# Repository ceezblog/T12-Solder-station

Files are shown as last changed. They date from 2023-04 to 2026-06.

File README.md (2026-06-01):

# T12-Solder-station

Just another Solder station using ATMega328 (or variant)

## 1. Main board
- Support only T12 tip that has ~4ohm~ 8ohm heater
- Only work with ATMega168, ATMega328 or newer ATMega328PB
- Use IRF4905 (P-channel) to turn on/off heat element
- Use LMV321 for amplifying thermocouple voltage, not the best but cheap and reliable
- Use buck converter mini360 and linear regulator AMS1117 for high efficiency
- Encoder to control the temperature
- Use homemade opto switch, just a pair of IR LED and IR Reciever Diode (or phototransistor)
- Only need 2 wires to the tip's heat element

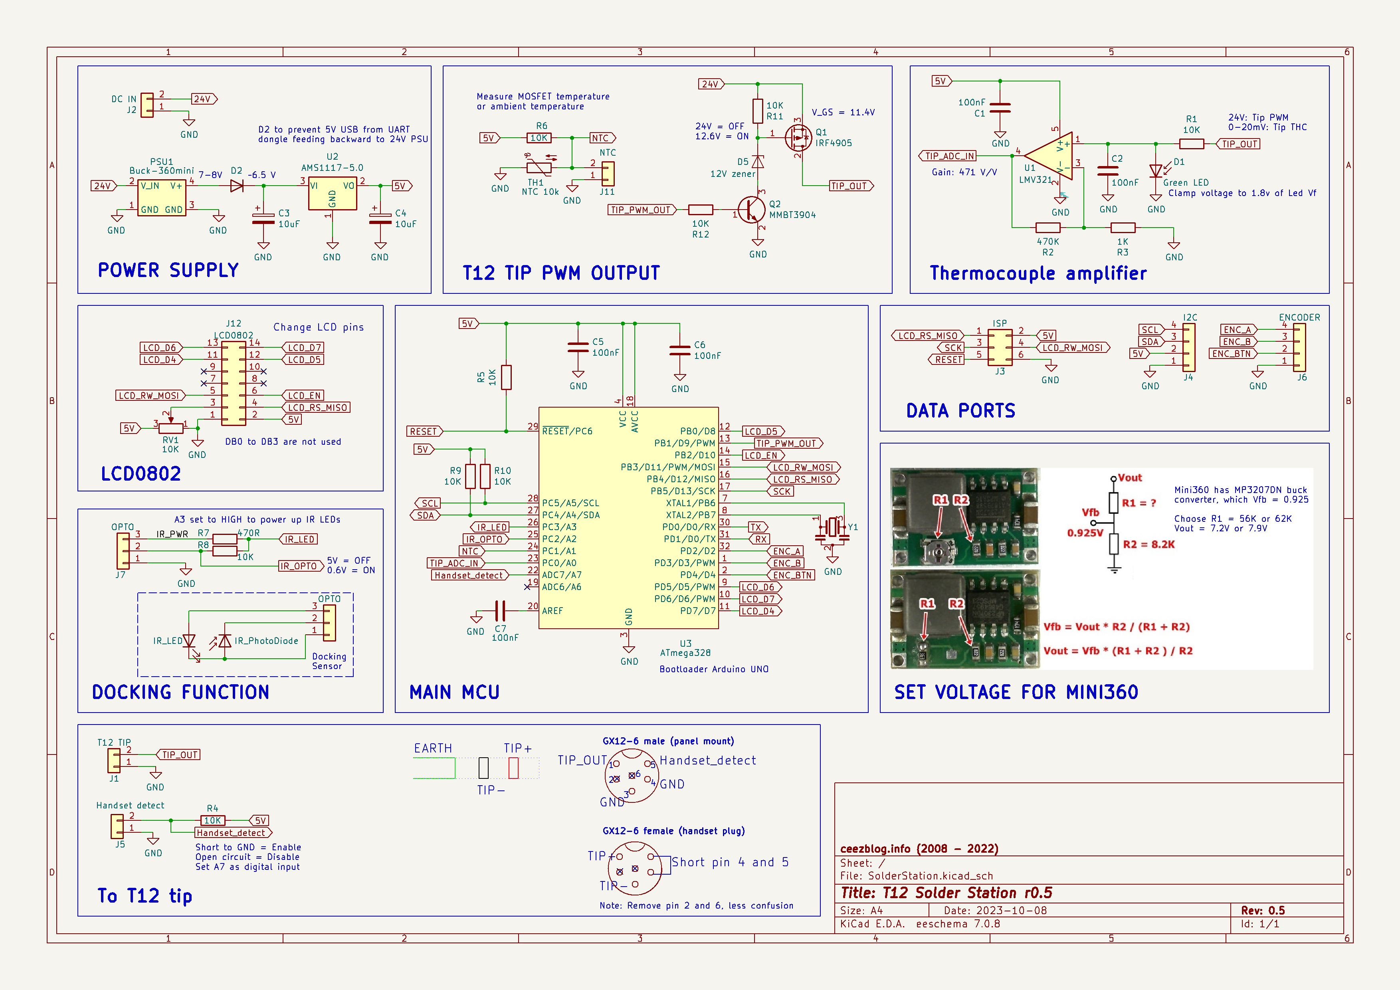
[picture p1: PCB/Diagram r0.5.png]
schematic

Pdf version here <a href='PCB/SolderStation_r0.5.pdf'>SolderStation_r0.5.pdf</a>

## 2. Switching PSU
- The 3D printed enclosure only supports this power supply model WX-DC2412, search aliexpress for "WX-DC2412 24V 4A"
- There are a few variants of this power supply have the same mounting holes which work just fine
- Always pick PSU 30% more power capable when your system full-load, ie: full-load 3A -> choose 4A PSU
- Laptop adaptor usually is 19V, using 8ohm tip -> 45w, while 24V PSU will delivery 72w at the tip
- It's better if you have earth prong from main AC 240V connect to the tip, but not neccessary
- Just a warm note: Do not attemp to modify or fix switching PSU, don't try messing with AC 240V

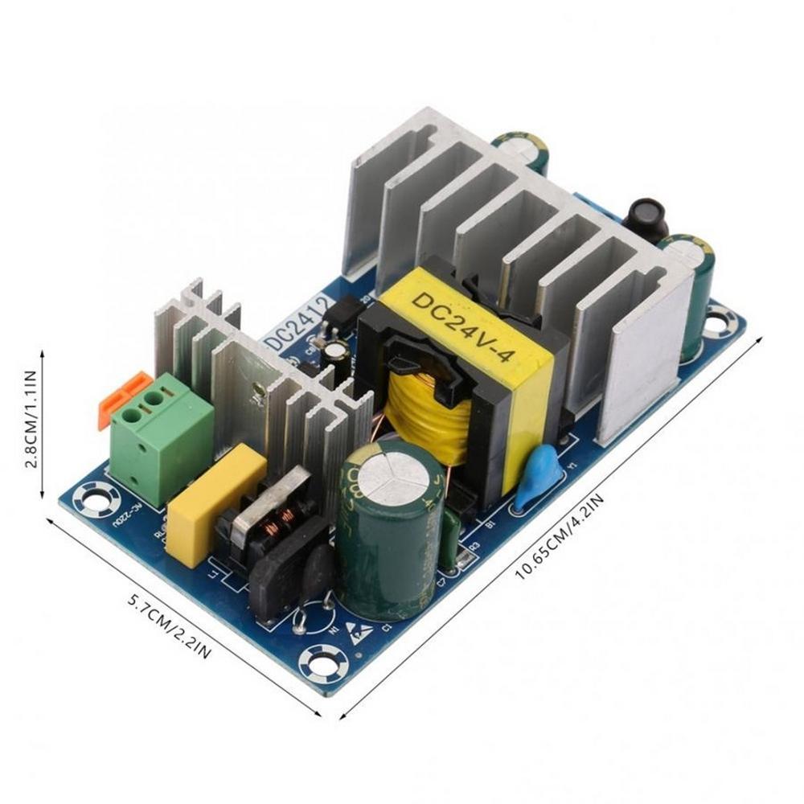
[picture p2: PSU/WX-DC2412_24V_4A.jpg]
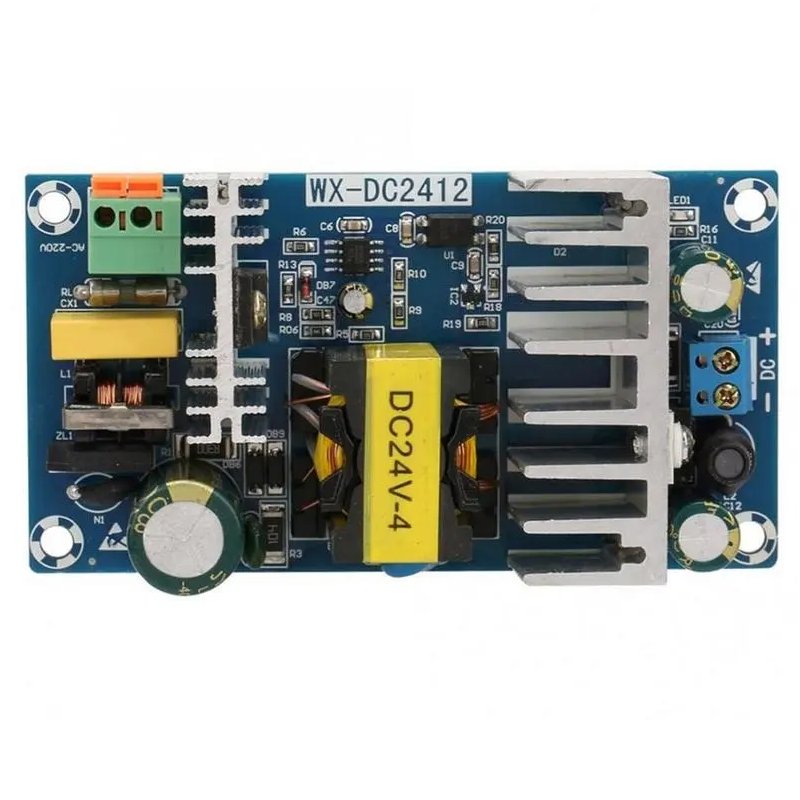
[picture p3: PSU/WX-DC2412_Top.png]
 

## 4. Display
- Only support LCD0802 - 8 char 2 line Character LCD, the main board was designed to piggyback on the LCD
- It is possible to use SSD1306 display via I2C or bitbang SPI for ILI9341 display controller but I haven't written code for this. 
- The 0802 is way nicer in my opinion
- PCB was designed for direct PCB to PCB plug-in (dupon header male and female) to the 14pin version of LCD0802
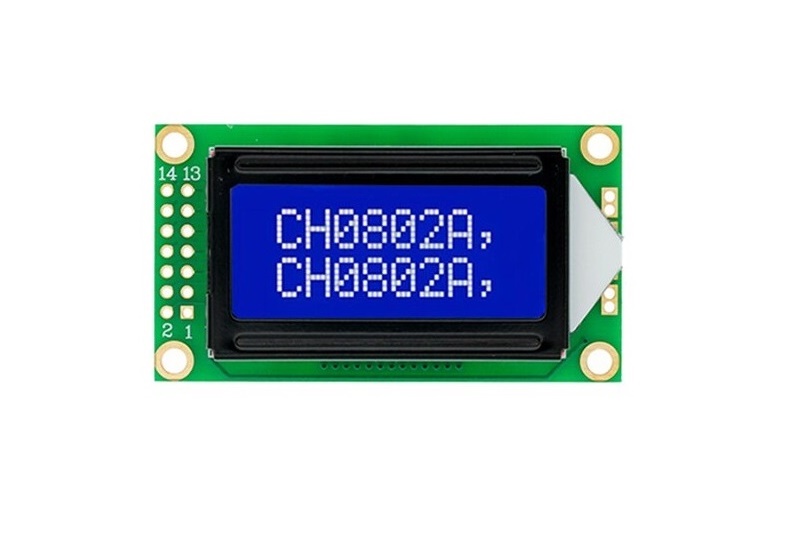
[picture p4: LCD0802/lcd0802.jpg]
LCD0802


- There is 16pin version of LCD0802, which offset the pins. This won't be direct plug-in. It can be done but a bit of hack-ish solution:
  - Solder a tall header (2x7) and bend all 14 metal pins in an awkward way so that 4 screws in the corner would be in the right spot.
  - 2 extra pins (pin 15-16) are for the backlight and are not connected to controller blob. So the code won't be able to turn on/off backlight at will. There are 2 jumpers near the backlight LED (that connects to the LED and to the controller blob), just short those 2 jumpers and don't touch other jumpers. In my case, it is J3 and J4. Different vendors have different markings.
  - While you are there, replace 0R with 330R to lower down backlight current draw as well. It probably is 100R and 0R which I find a bit high (about 25mA @ 5V for white LED). Comfortable range for a small LED like that is around 5-20mA which your eyes won't be able to tell the difference in brightness, but your phone's camera will say otherwise.

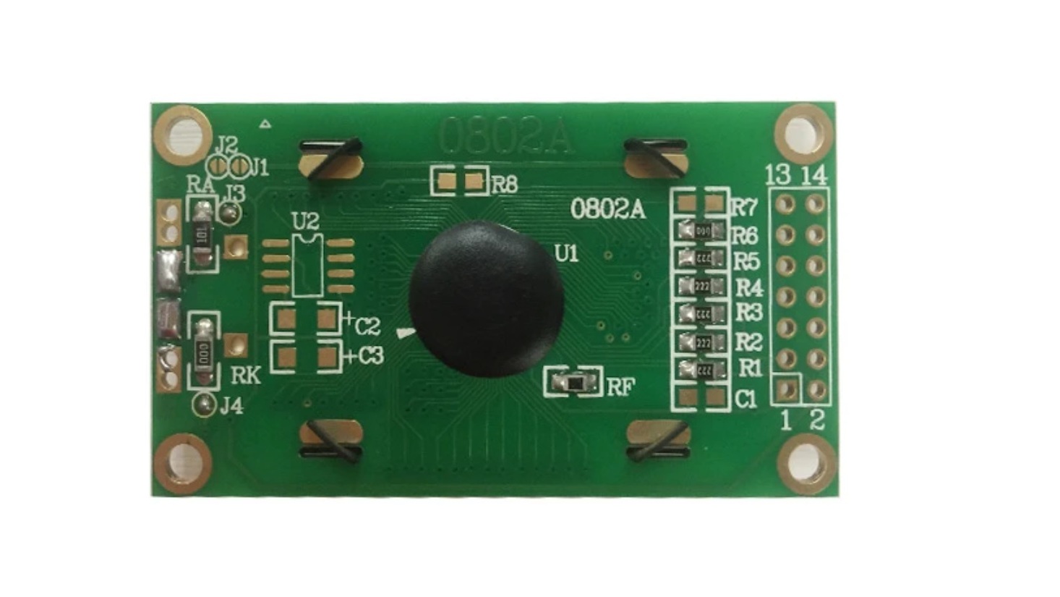
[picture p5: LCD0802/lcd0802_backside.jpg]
LCD0802_backside


## 5. Enclosure
- All 3D printed, except for the rubber feet to stop this box from sliding when pressing power button
- Housing a nice Switching PSU, no need for discrete power brick which you can't turn off from this box
- Include stand for the handle with docking mechanism using homemade opto switch
- Include opto switch housing, just need a pair of IR LED and IR receiver diode.
 
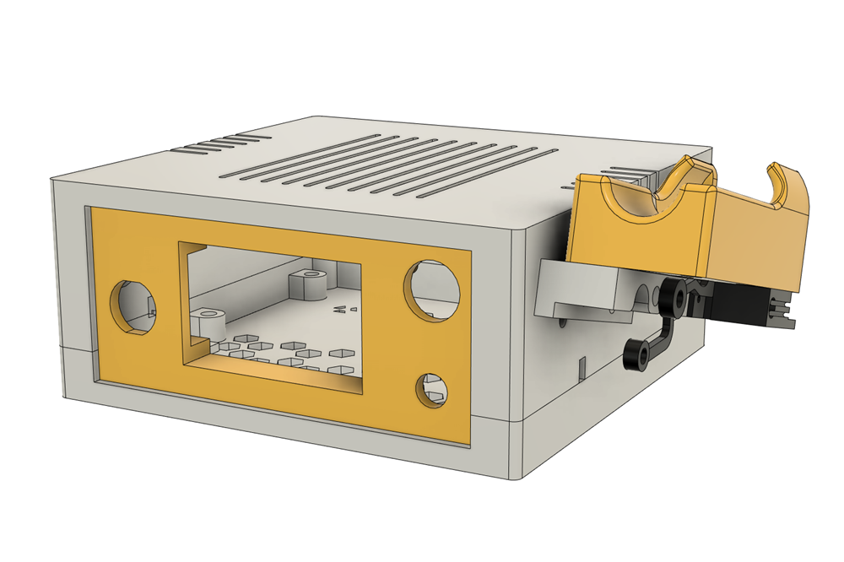
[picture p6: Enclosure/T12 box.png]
3D printed Enclosure

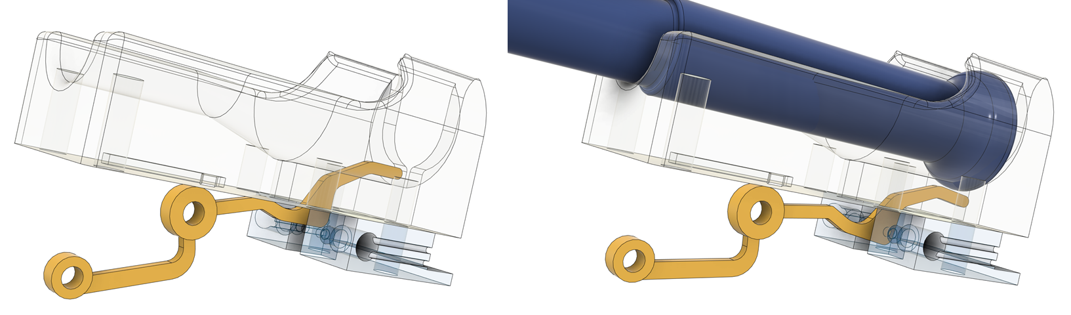
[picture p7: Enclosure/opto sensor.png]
3D printed Enclosure


## 6. Firmware and calibration
- Using Arduino IDE and MiniCore for ATMEGA328PB (new variant that you can buy readily these day - 2023) while classic Arduino is ATMEGA328
- There are main firmware and calibration firmware for you to play with your own calibration
- Only ATMega328 and variant is supported because of low level code to config timer, pwm, interrupts...
- Only three libraries are used: **avr/interrupt.h, EEPROM.h and LiquidCrystal.h**
- Thermocouple in T12 tip is unknown, not K-type nor C-type, so you can't really use off-the-shelf themocouple amplifier
- I calibrate it by tabulating ADC readings against multiple temperatures, then plotting the chart in excel to find the trend equation: T = ADC*0.403 + 49.6
- This formular only applies to the amplifier that has gain of 471V/V and 8ohm T12 tip, if you have 4ohm tip, use with caution
- The downside of 10bit ADC is we cannot measure anything below 48mV which is around 50°C
- This guy has some nice work on debunk the myth T12 tip is K-type https://hackaday.io/project/94905-hakko-revenge/log/144548-hakko-t12-thermocouple-is-not-type-k
- ~Mine is a bit glitchy with EEPROM, sometime it doesn't remember docking function is ON after power off~ I just had a bad M328PB chip
- Doesn't implement any thermal runaway protection, but code such feature is not that hard:
  + At every tick, check if temp increase while powering - Heater dead or wrong pin connected if temperature stays the same
  + Check temperature difference if too great after 3-5s heat up - Probably different thermocouple in the tip
 
## 7. T12 Handle
- It would work with pretty much any T12 handle you can buy, but the stand probably won't accept many of them
- I have 2 stand designs for handles I have, check the cross section diameter of the handle before print
- If you want the original aviation GX plug come with the handle, then just short J5 by a jumper and by-pass check for handle
- A standalone iron handle stand <a href="https://ceezblog.com/revisit-my-homemade-t12-soldering-station">blog post at ceezblog.com</a>
 
 ## 8. Put everything together
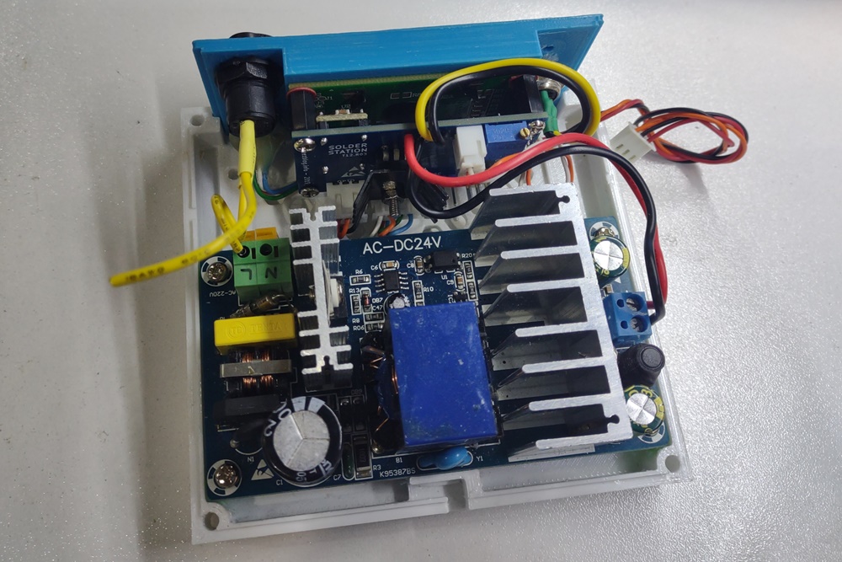
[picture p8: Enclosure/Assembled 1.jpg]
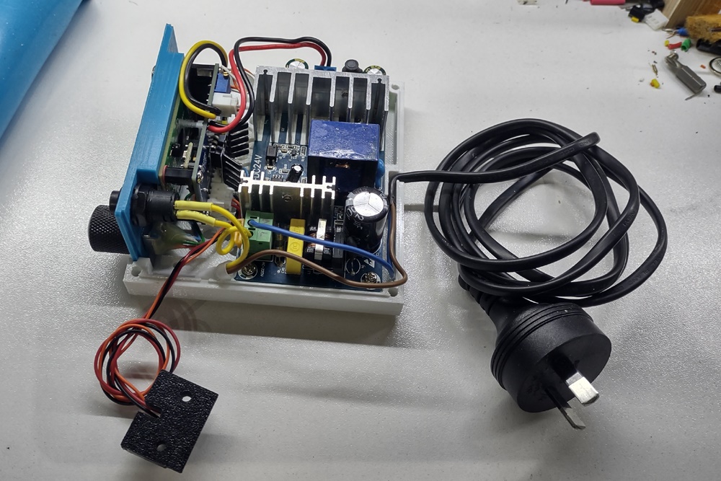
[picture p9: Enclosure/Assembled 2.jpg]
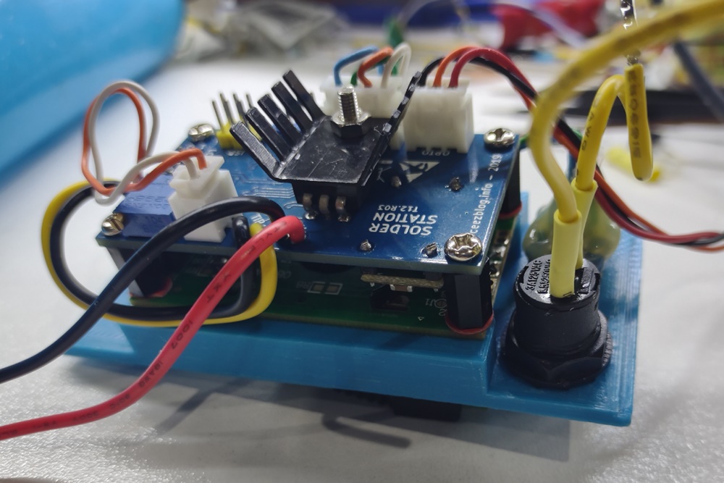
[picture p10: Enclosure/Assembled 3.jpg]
  
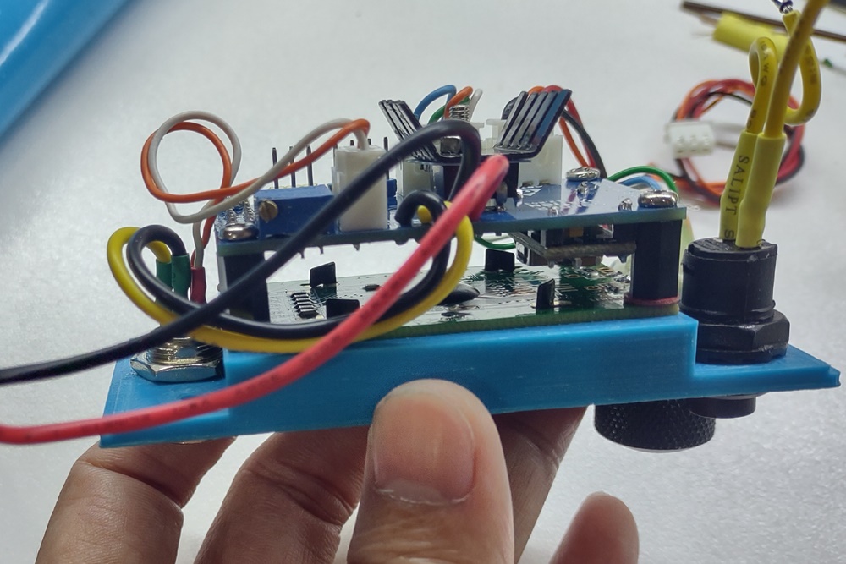
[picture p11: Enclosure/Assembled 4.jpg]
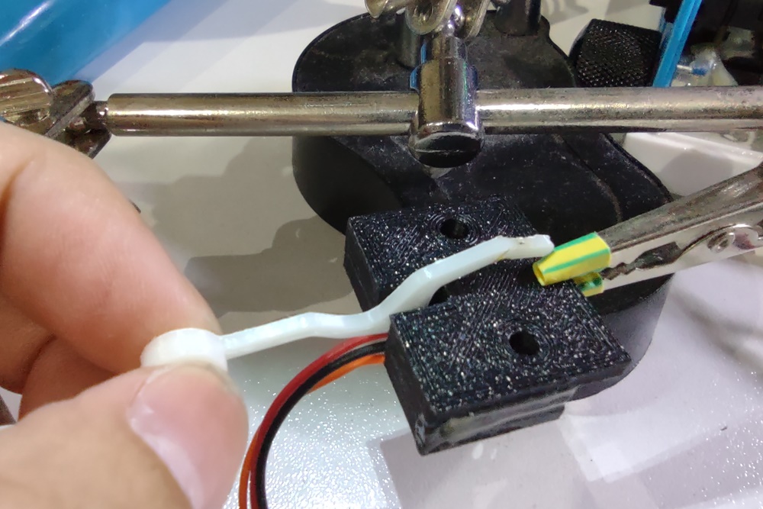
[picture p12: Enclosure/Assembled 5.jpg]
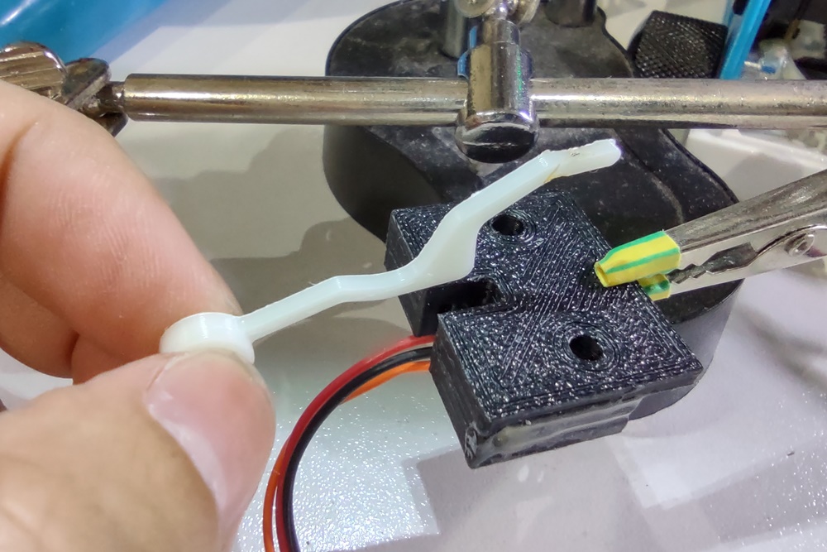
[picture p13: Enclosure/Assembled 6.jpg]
  
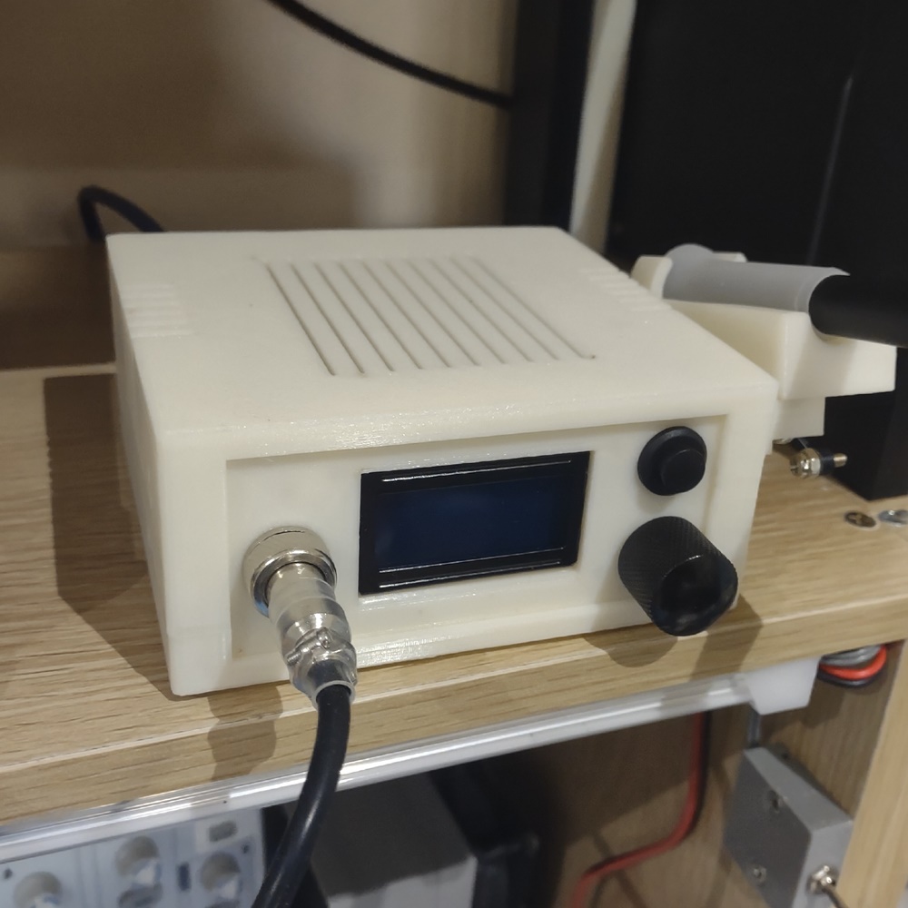
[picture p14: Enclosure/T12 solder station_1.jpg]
3D printed Enclosure
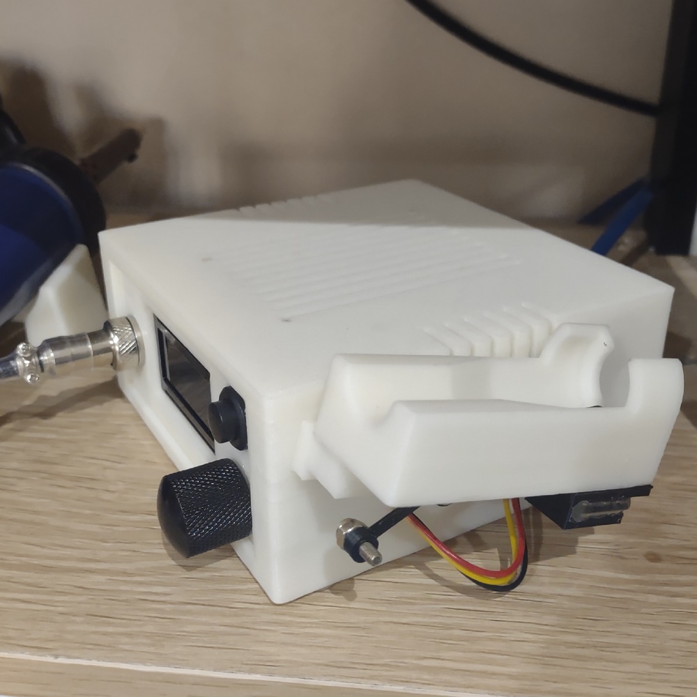
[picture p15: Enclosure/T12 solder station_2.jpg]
3D printed Enclosure
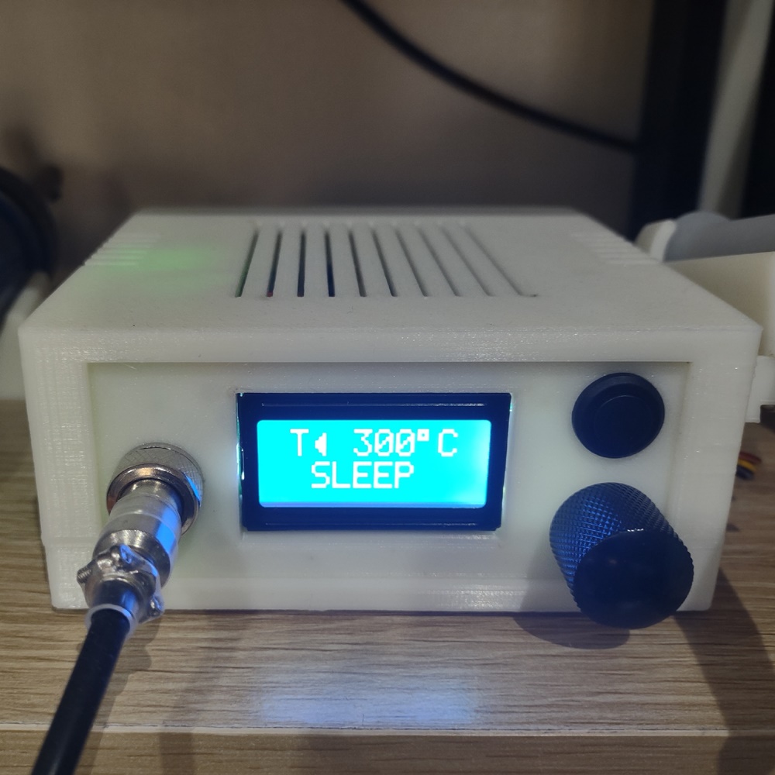
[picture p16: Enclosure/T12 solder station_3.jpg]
3D printed Enclosure
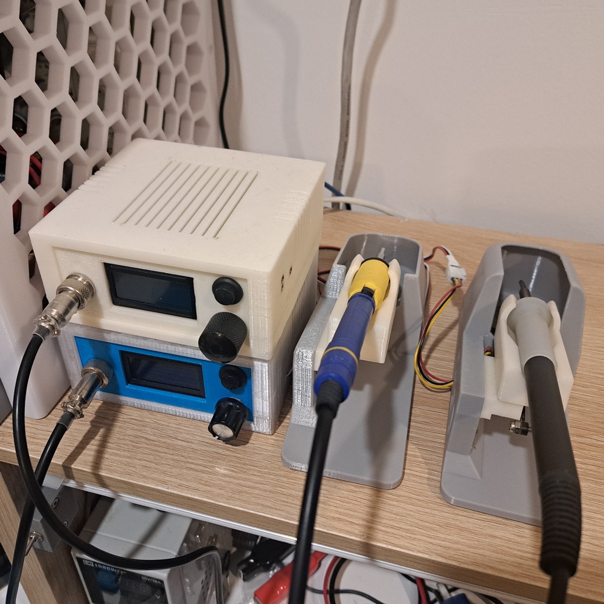
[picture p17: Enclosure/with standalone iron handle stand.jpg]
3D printed Enclosure
   3D printed Enclosure 3D printed Enclosure

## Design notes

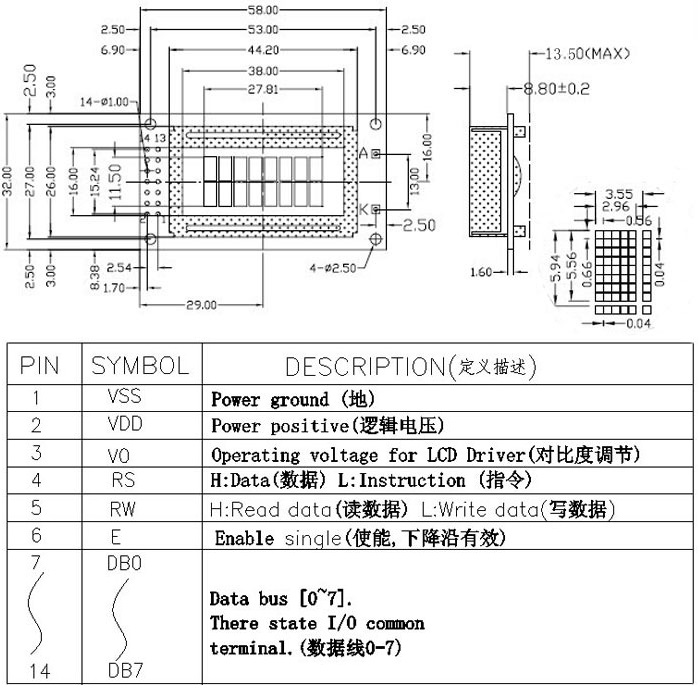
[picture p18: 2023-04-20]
LCD0802/lcd0802-0.jpg

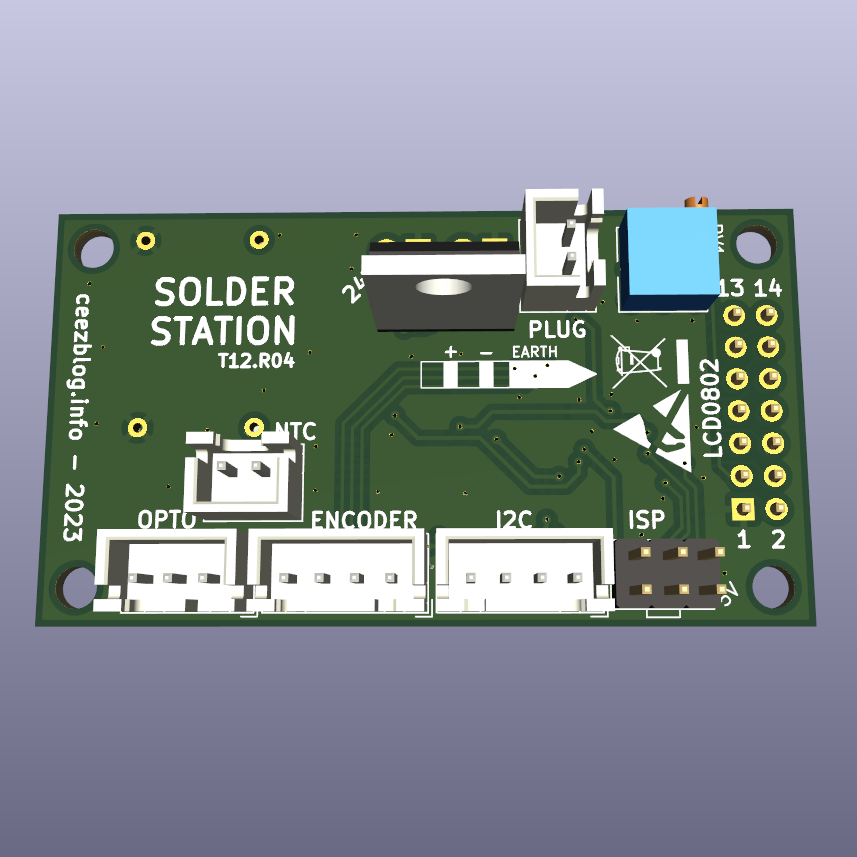
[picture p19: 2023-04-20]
PCB/Render 3.png

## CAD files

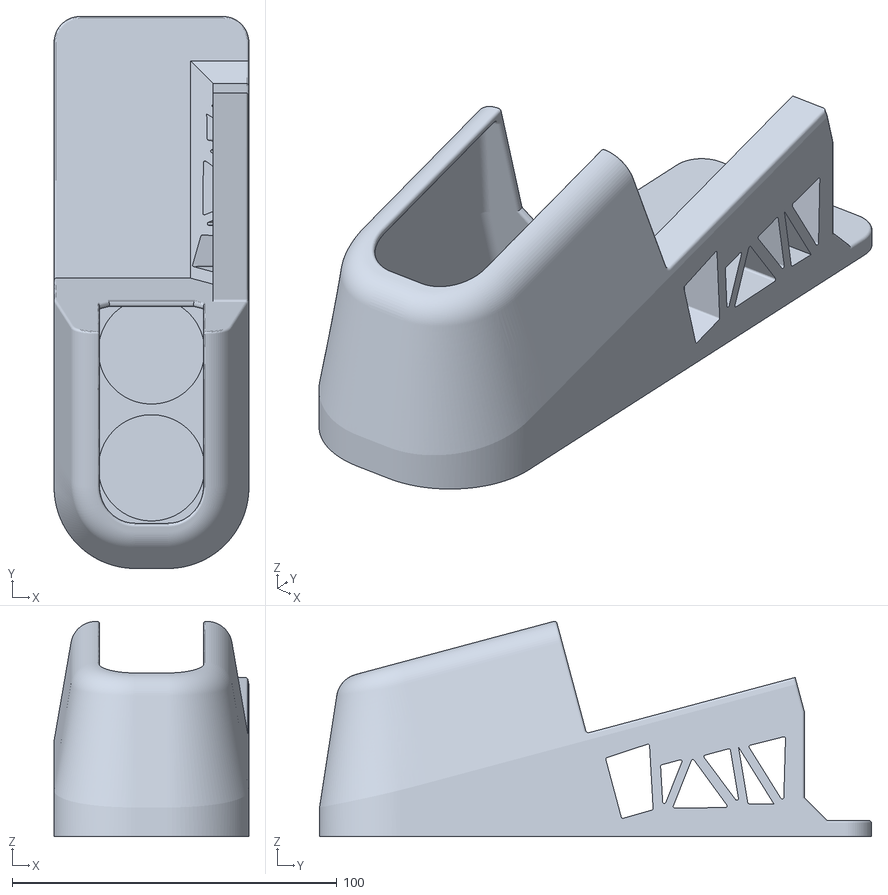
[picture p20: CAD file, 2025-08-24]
Enclosure/STL/iron handle stand - standalone - frame only.stl
60.0 x 170.0 x 66.3

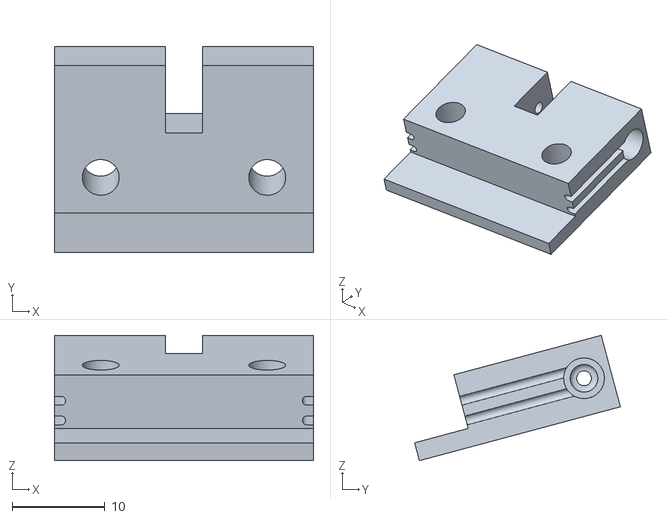
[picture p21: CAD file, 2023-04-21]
Enclosure/STL/Sensor2.stl
28.0 x 22.3 x 13.6

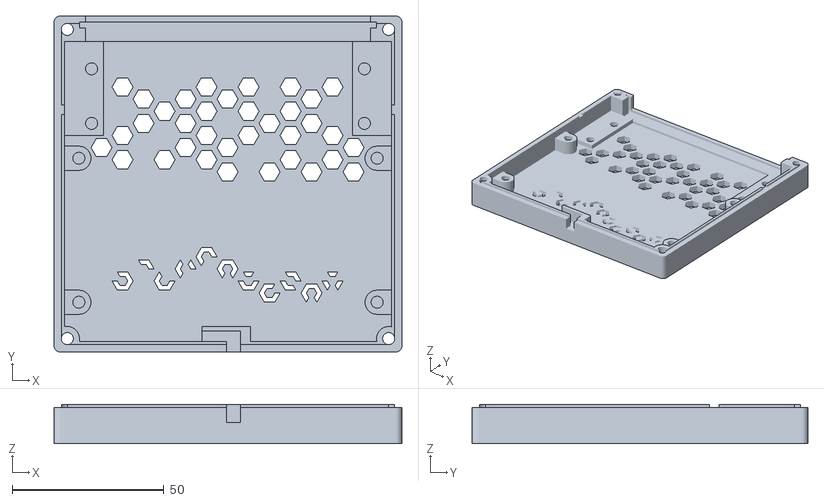
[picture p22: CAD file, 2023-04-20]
Enclosure/STL/Bottom.stl
114.8 x 110.8 x 13.0

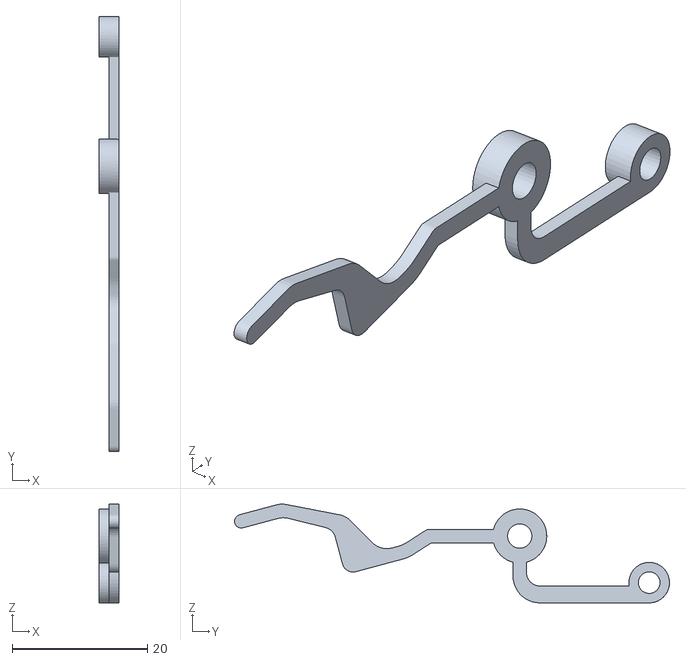
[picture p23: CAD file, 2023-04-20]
Enclosure/STL/Arm 2.stl
3.00 x 64.3 x 14.6

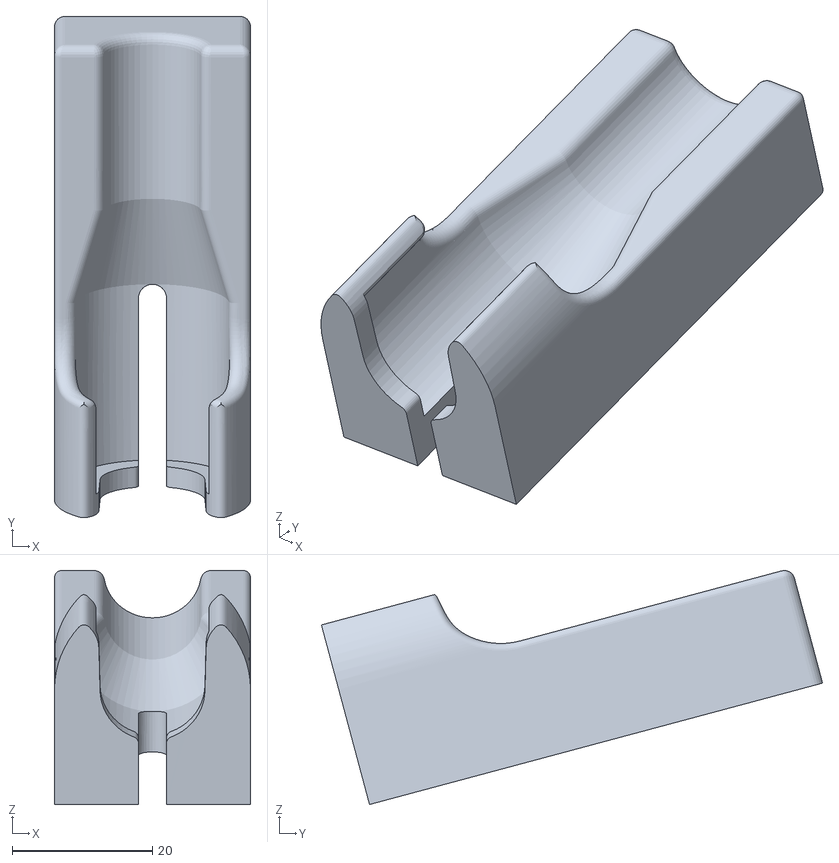
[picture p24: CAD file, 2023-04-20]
Enclosure/STL/Handle stand 2 - larger handle.stl
28.0 x 71.6 x 33.4

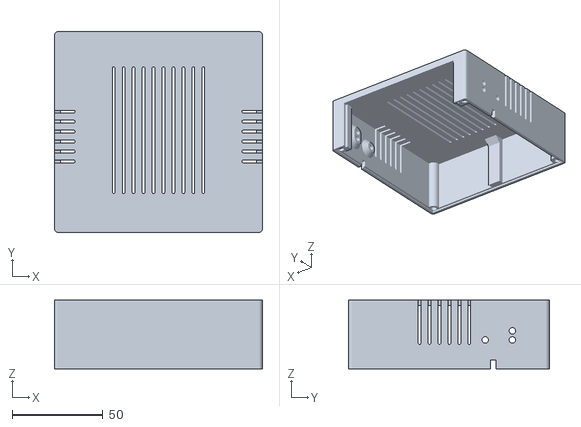
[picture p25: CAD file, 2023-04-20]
Enclosure/STL/Top.stl
114.8 x 110.8 x 38.0

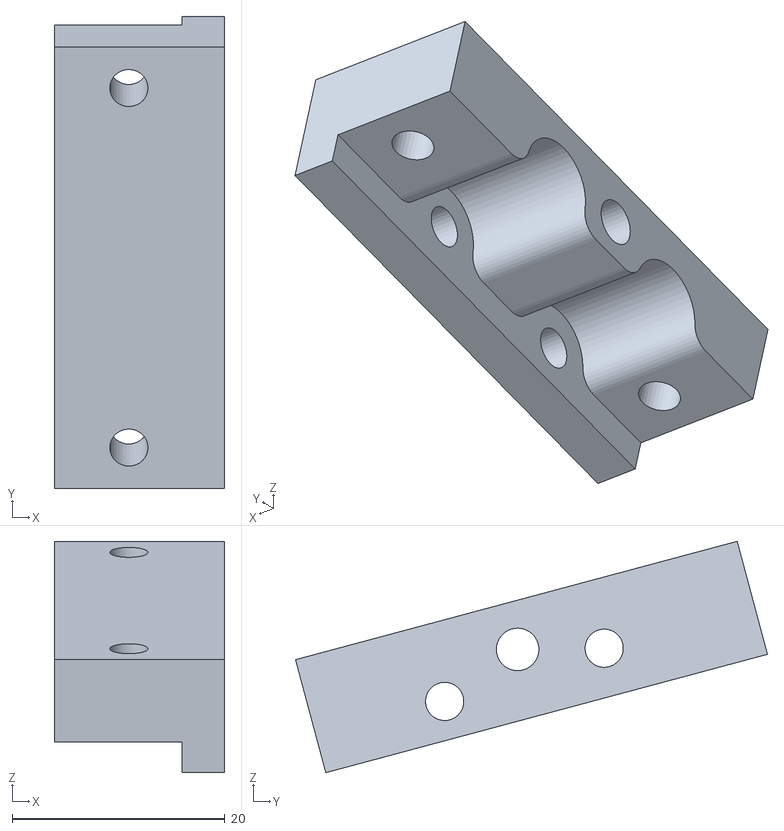
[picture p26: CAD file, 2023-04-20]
Enclosure/STL/Bracket 2.stl
16.0 x 44.4 x 21.8

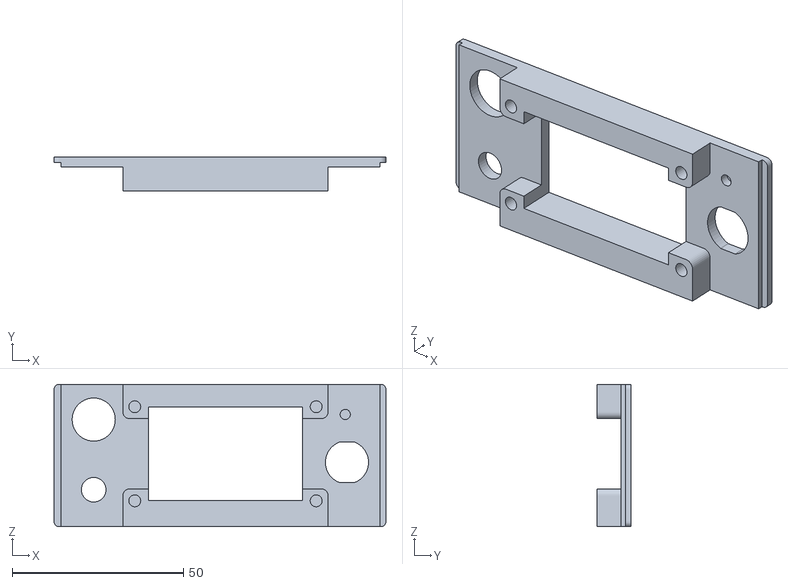
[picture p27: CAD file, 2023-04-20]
Enclosure/STL/Face.stl
97.0 x 10.0 x 41.6

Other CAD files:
Enclosure/STL/T12 box.f3d

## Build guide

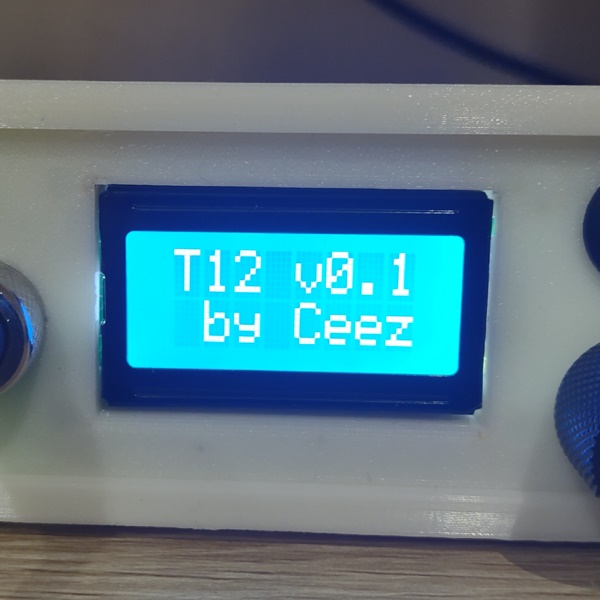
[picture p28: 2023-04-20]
Enclosure/T12 solder station_0.jpg

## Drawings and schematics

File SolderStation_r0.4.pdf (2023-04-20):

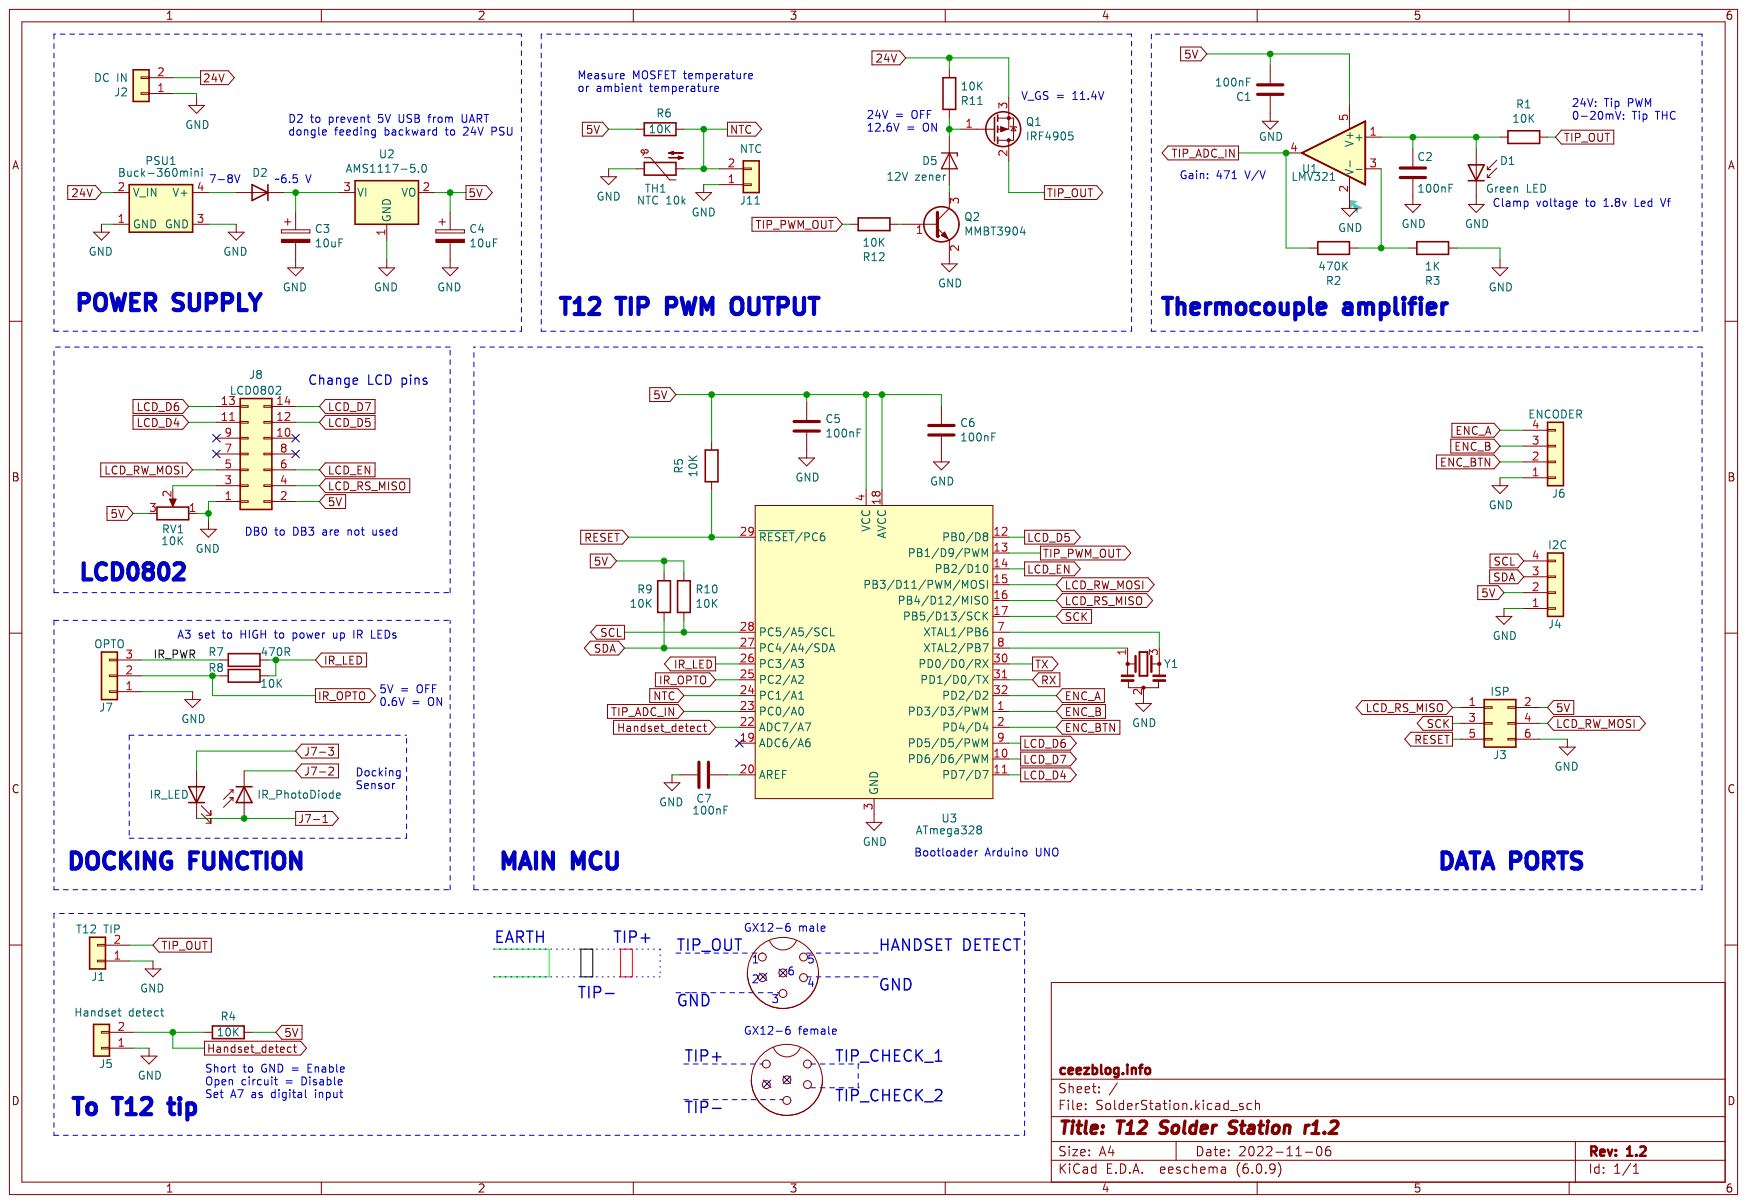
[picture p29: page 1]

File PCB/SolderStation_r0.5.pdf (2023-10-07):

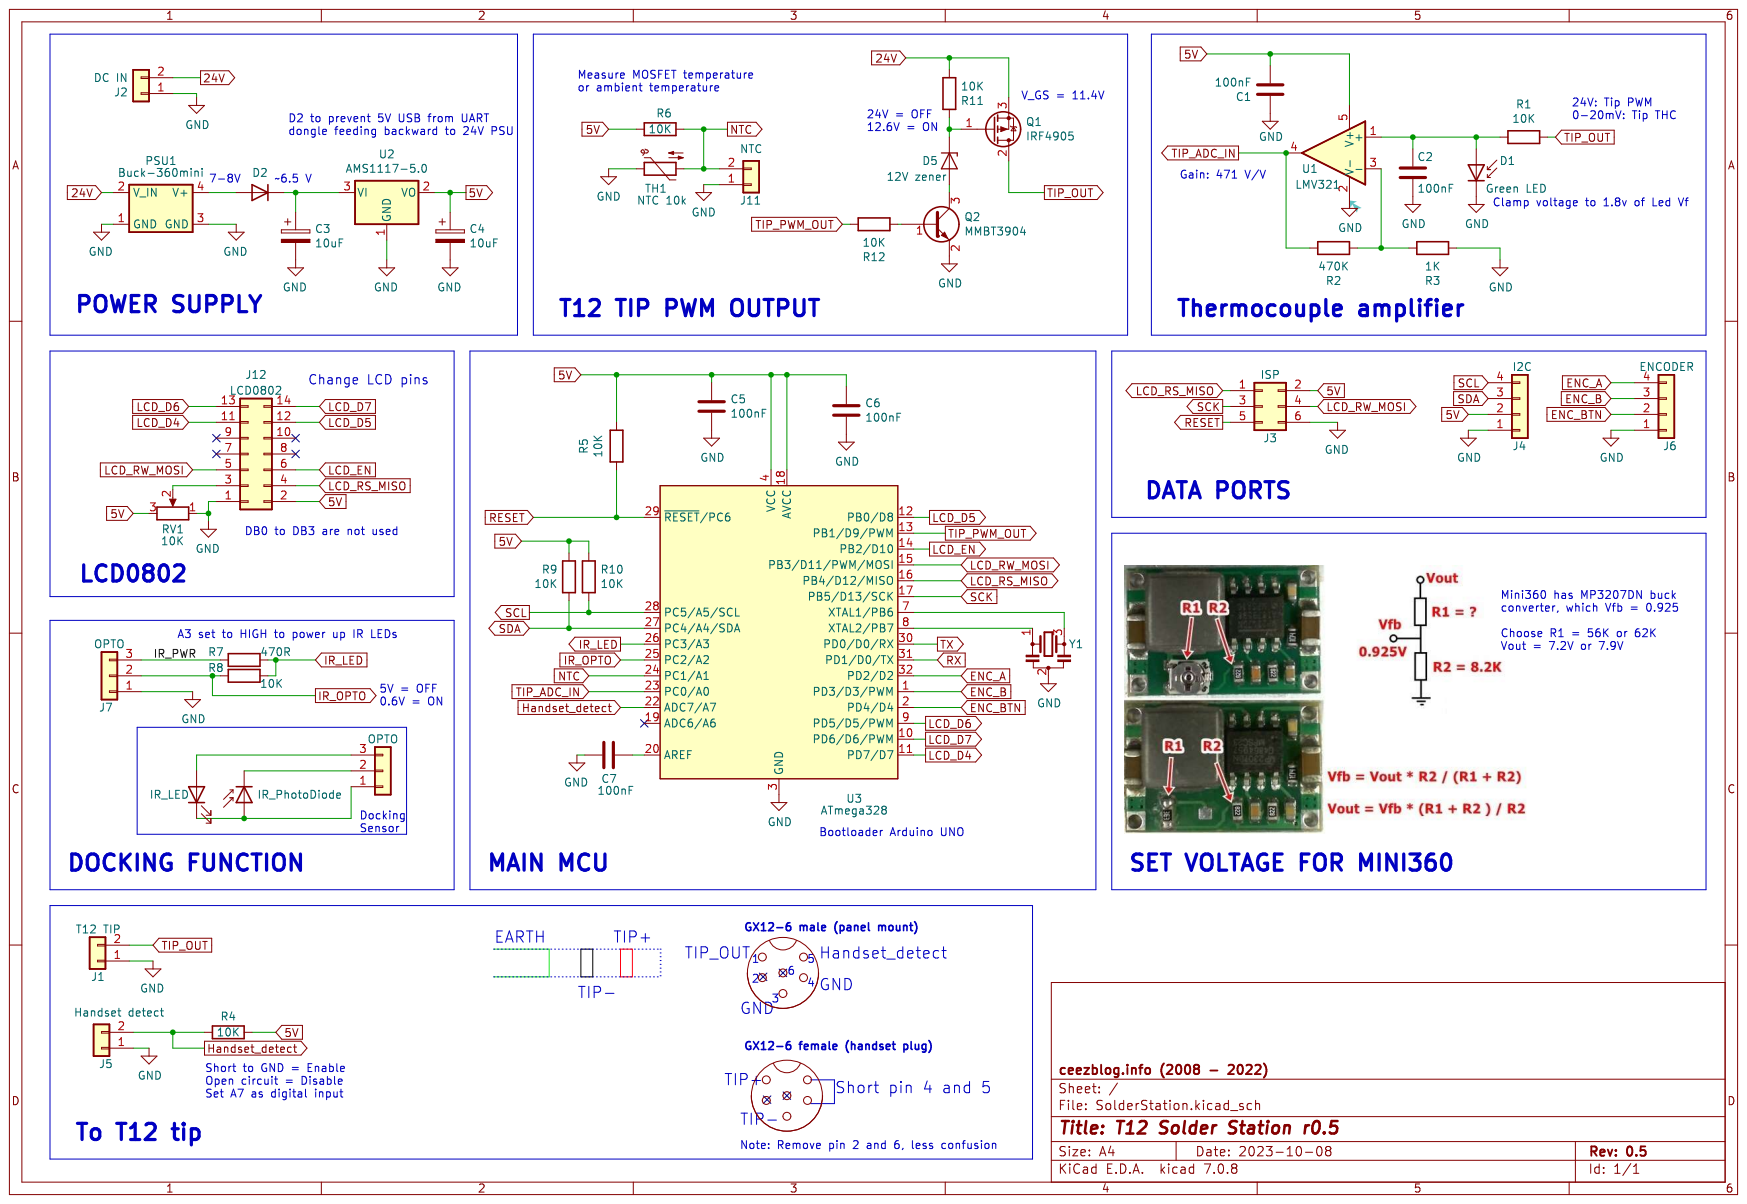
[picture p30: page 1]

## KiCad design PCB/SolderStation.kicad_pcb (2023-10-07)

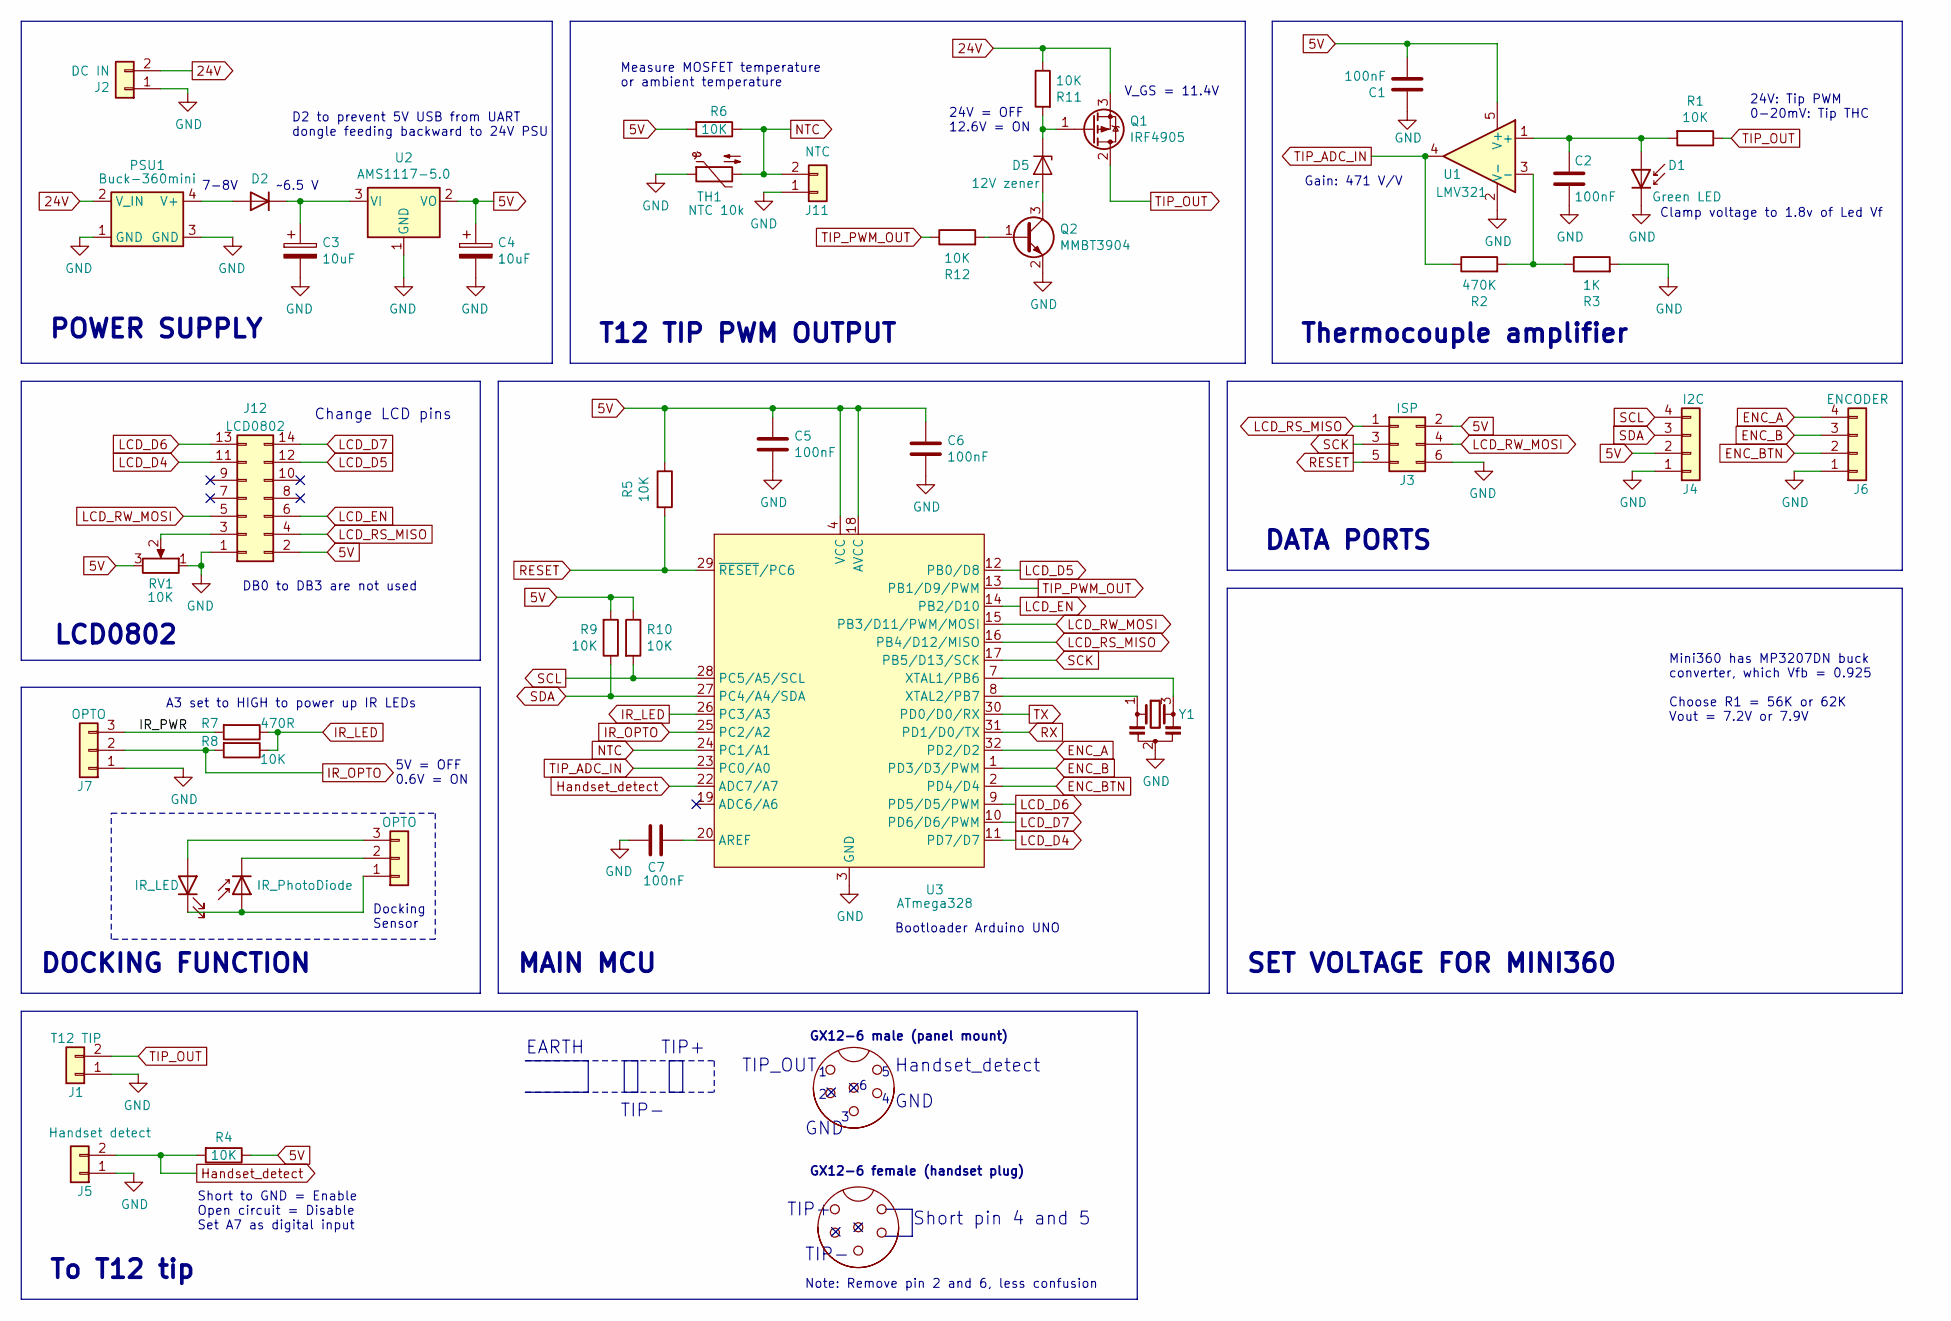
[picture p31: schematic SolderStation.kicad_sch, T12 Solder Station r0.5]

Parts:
C1, C2, C5, C6, C7: 100nF; C_0805_2012Metric
C3, C4: 10uF; CP_EIA-3528-12_Kemet-T
D1: Green LED; LED_0805_2012Metric
D2: Schottky; D_SMB
D3: IR_LED
D4: IR_PhotoDiode
D5: 12V zener; D_SOD-323
J1: T12 TIP; PinSocket_1x02_P2.54mm_Vertical
J2: DC IN; PinSocket_1x02_P2.54mm_Vertical
J3: ISP; PinHeader_2x03_P2.54mm_Vertical
J4: I2C; JST_XH_B4B-XH-A_1x04_P2.50mm_Vertical
J5: Handset detect; JST_XH_B2B-XH-A_1x02_P2.50mm_Vertical
J6: ENCODER; JST_XH_B4B-XH-A_1x04_P2.50mm_Vertical
J7, J8: OPTO; JST_XH_B3B-XH-A_1x03_P2.50mm_Vertical
J9: Aviation-GX12-6; ESD-Logo_6.6x6mm_SilkScreen
J10: Aviation-GX12-6; WEEE-Logo_4.2x6mm_SilkScreen
J11: NTC; JST_XH_B2B-XH-A_1x02_P2.50mm_Vertical
J12: LCD0802
PSU1: Buck-360mini; Mini360_DC-DC
Q1: IRF4905; TO-220-3_Minimal
Q2: MMBT3904; SOT-23
R1, R4, R5, R6, R8, R9, R10, R11, R12: 10K; R_0805_2012Metric
R2: 470K; R_0805_2012Metric
R3: 1K; R_0805_2012Metric
R7: 470R; R_0805_2012Metric
RV1: 10K; Potentiometer_Bourns_3266P_Horizontal
TH1: NTC 10k; R_0805_2012Metric
U1: LMV321; SOT-23-5
U2: AMS1117-5.0; SOT-223-3_TabPin2
U3: ATmega328; TQFP-32_7x7mm_P0.8mm
Y1: Resonator_Small; Resonator_SMD_muRata_CSTxExxV-3Pin_3.0x1.1mm

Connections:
5V: C1.2, C4.1, C5.1, C6.1, J3.2, J4.2, J12.2, R4.1, R5.1, R6.2, R9.2, R10.1, RV1.3, U1.5 (V+), U2.2 (VO), U3.4 (VCC), U3.6 (VCC), U3.18 (AVCC)
24V: J2.2, PSU1.2 (V_IN), Q1.3 (S), R11.1
/IR_PWR: J7.3, R7.2
ENC_A: J6.4, U3.32 (PD2/D2)
ENC_B: J6.3, U3.1 (PD3/D3/PWM)
ENC_BTN: J6.2, U3.2 (PD4/D4)
GND: C1.1, C2.2, C3.2, C4.2, C5.2, C6.2, C7.2, D1.1 (K), J1.1, J2.1, J3.6, J4.1, J5.1, J6.1, J7.1, J11.1, J12.1, PSU1.1 (GND), PSU1.3 (GND), Q2.2 (E), R3.2, RV1.1, TH1.1, U1.2 (V-), U2.1 (GND), U3.3 (GND), U3.5 (GND), U3.21 (GND), Y1.2
Handset_detect: J5.2, R4.2, U3.22 (ADC7/A7)
IR_LED: R7.1, R8.1, U3.26 (PC3/A3)
IR_OPTO: J7.2, R8.2, U3.25 (PC2/A2)
LCD_D4: J12.11, U3.11 (PD7/D7)
LCD_D5: J12.12, U3.12 (PB0/D8)
LCD_D6: J12.13, U3.9 (PD5/D5/PWM)
LCD_D7: J12.14, U3.10 (PD6/D6/PWM)
LCD_EN: J12.6, U3.14 (PB2/D10)
LCD_RS_MISO: J3.1, J12.4, U3.16 (PB4/D12/MISO)
LCD_RW_MOSI: J3.4, J12.5, U3.15 (PB3/D11/PWM/MOSI)
NTC: J11.2, R6.1, TH1.2, U3.24 (PC1/A1)
unnamed: C2.1, D1.2 (A), R1.2, U1.1 (+)
unnamed: D2.2 (A), PSU1.4 (V+)
unnamed: C3.1, D2.1 (K), U2.3 (VI)
unnamed: D3.1 (K), D4.2 (A), J8.1
unnamed: D3.2 (A), J8.3
unnamed: D4.1 (K), J8.2
unnamed: D5.2 (A), Q2.3 (C)
unnamed: D5.1 (K), Q1.1 (G), R11.2
unnamed: J12.3, RV1.2
unnamed: Q2.1 (B), R12.2
unnamed: R2.2, R3.1, U1.3 (-)
unnamed: C7.1, U3.20 (AREF)
unnamed: U3.7 (XTAL1/PB6), Y1.3
unnamed: U3.8 (XTAL2/PB7), Y1.1
RESET: J3.5, R5.2, U3.29 (~RESET/PC6)
RX: U3.31 (PD1/D0/TX)
SCK: J3.3, U3.17 (PB5/D13/SCK)
SCL: J4.4, R10.2, U3.28 (PC5/A5/SCL)
SDA: J4.3, R9.1, U3.27 (PC4/A4/SDA)
TIP_ADC_IN: R2.1, U1.4, U3.23 (PC0/A0)
TIP_OUT: J1.2, Q1.2 (D), R1.1
TIP_PWM_OUT: R12.1, U3.13 (PB1/D9/PWM)
TX: U3.30 (PD0/D0/RX)

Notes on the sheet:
Mini360 has MP3207DN buck converter, which Vfb = 0.925 Choose R1 = 56K or 62K Vout = 7.2V or 7.9V
Note: Remove pin 2 and 6, less confusion
Thermocouple amplifier
POWER SUPPLY
Measure MOSFET temperature or ambient temperature
5V = OFF 0.6V = ON
GND
DB0 to DB3 are not used
~6.5 V
TIP_OUT
Docking Sensor
DOCKING FUNCTION
A3 set to HIGH to power up IR LEDs
MAIN MCU
TIP-
Gain: 471 V/V
Change LCD pins
EARTH
7-8V
24V: Tip PWM 0-20mV: Tip THC
24V = OFF 12.6V = ON
GX12-6 male (panel mount)
To T12 tip
Short to GND = Enable Open circuit = Disable Set A7 as digital input
D2 to prevent 5V USB from UART dongle feeding backward to 24V PSU
Handset_detect
T12 TIP PWM OUTPUT
LCD0802
V_GS = 11.4V
Clamp voltage to 1.8v of Led Vf
Bootloader Arduino UNO
TIP+
Short pin 4 and 5
GX12-6 female (handset plug)
SET VOLTAGE FOR MINI360
DATA PORTS

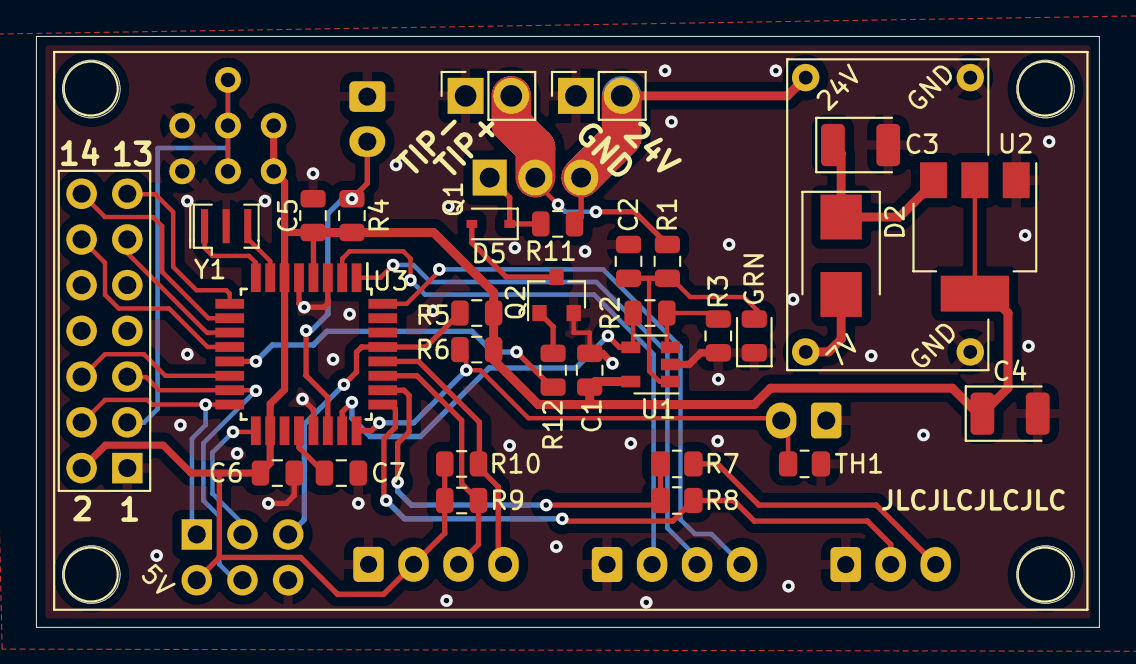
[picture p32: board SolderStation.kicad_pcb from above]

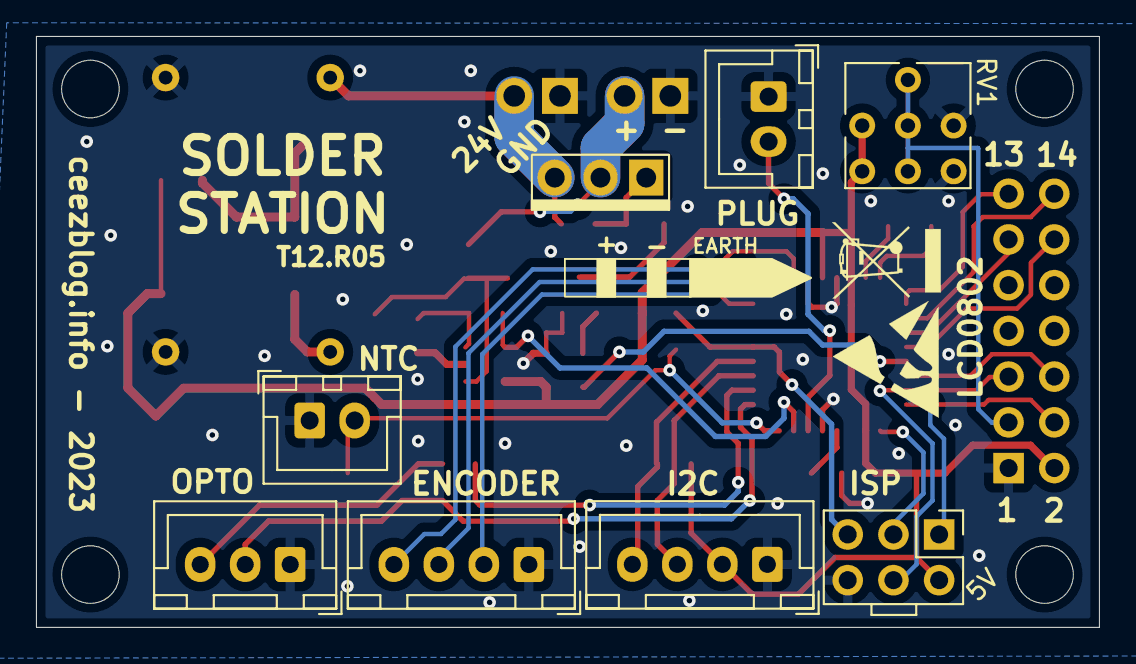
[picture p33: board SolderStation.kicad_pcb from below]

Board: 2 copper layers, 59.1 x 32.8 mm, 42 parts (10 on the bottom side), 36 nets.

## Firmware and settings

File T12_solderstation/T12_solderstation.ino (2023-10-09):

///////////////////////////////////////////////////////////////////////////////
// T12 solder station r0.3
//	Cee'z 30 Mar 2023
//
//	///////////////   ////////////////
//	//  T12 v0.5 //   //  T< 200*C  //
//	//   by Ceez //   //  H> 200*C  //
//	///////////////   ////////////////
//
///////////////////////////////////////////////////////////////////////////////
// Target MCU: ATMega328PB - MiniCore - Arduino IDE
// Clock: Ext 16MHz
//
// Character LCD 8x2 - board r0.3
//		Fn:      5V+    GND   Enable  RS    R/W   Contrast  DB4 DB5 DB6 DB7	
//		Pin no:	 2      1     6       4     5     3         11  12  13  14
//		Arduino: 5v+    GND   D6      D5    D7    pot-10k   D10 D8  D12 D11
//
// The gain: (470K/1K)+1 = 471 v/v
//
// For TIP that has 8OHM heater:
//    T = 0.403*(A0) + 49.60 
// ADC = 1023 => T = 498*C, set limit to 490
// ADC = 1023 => T = 52*C, set limit to 490
// For TIP that has 4 OHM heater: 
//    T = 0.6089*(ADC-25) degC // this 

#define MAX_TEMP 495 // At max ADC 1023

//#define _DEBUG
#include <avr/interrupt.h>
#include <EEPROM.h>

// LCD configuration
#include <LiquidCrystal.h>
#define LCD_EN 6
#define LCD_RS 5
#define LCD_RW 7
#define LCD_D4 10
#define LCD_D5 8 
#define LCD_D6 12
#define LCD_D7 11
LiquidCrystal lcd(LCD_RS, LCD_RW, LCD_EN, LCD_D4, LCD_D5, LCD_D6, LCD_D7);

// custom chars
byte next_ch[8] = {B00000,B01000,B01100,B01110,B01110,B01100,B01000,B00000};
byte stop_ch[8] = {B00000,B11011,B11011,B11011,B11011,B11011,B11011,B00000};
byte back_ch[8] = {B00000,B00010,B00110,B01110,B01110,B00110,B00010,B00000};

// Pin configuration
#define TIP_AN A0 // tip voltage
#define NTC_AN A1 // Thermistor for air temp
#define OPTO A2
#define IR_LED A3
#define CHECK_TIP A7

#define ENCA 2    // D2
#define ENCB 3    // D3
#define ENCBTN 4  // D4
#define TIP_PWM 9 // D9

#define DOCK_TEMPERATURE 100
#define NUMSAMPLES 8

#define DOCK_T1 200 	// sleep temperature 200*C when docked
#define DOCK_T2 100	// sleep temperature after 2 minutes
#define DOCK_T3 0		// sleep temperature after 15 minutes // turn off heater completely

#define DOCK_TIMEOUT1	120000 	// 2*60=120 // 2 minutes
#define DOCK_TIMEOUT2	900000	// 15*60=900 // 15 minutes


// UPDATE RATE
#define HEATER_RATE 20
#define AIR_RATE 1000
#define OPTO_CHECK_RATE 5

// Thermistor reading
#define SERIES_RESISTOR 10000
#define VCC 4950
#define NTC_NOMINAL 10000      
#define NTC_TEMP_NOMINAL 25   
#define B_COEFF 3950


// Global variable
bool bSleep;
bool bHeating;
bool bHUpdate;
bool bAirUpdate;
bool bOptoCheck;
bool bEnableOpto;

bool bAir;
bool bTipFail;
bool bSetUpdate;


int16_t target_T; //target temperature
int16_t tip_T;
int16_t air_T;

// Counting time
uint16_t HeaterTick;
uint16_t AirTick;
uint16_t OptoTick;


// Encoder stuff
volatile byte A_STATE;
volatile byte B_STATE;
volatile byte RT_CCW;
volatile byte RT_CW;
volatile byte BT_PREV_STATE = HIGH;

// Atmega328, not sure for ATMEGA328PB
// PCINT0_vect for D8 to D13
// PCINT1_vect for A0 to A5
// PCINT2_vect for D0 to D7

// bouncing stuffs
unsigned long btDown_tm;
unsigned long btUp_tm;
unsigned long rot_next_tm;   
unsigned long rot_prev_tm;

// docking timeout
unsigned long dock_tm;
uint8_t dock_cnt; 	//count how many times docking to determine docking function
bool dock_last_status;


// powering OPTO by an IO pin
#define OPTO_ON() digitalWrite(IR_LED, HIGH)   
#define OPTO_OFF() digitalWrite(IR_LED, LOW)
#define isDocking() digitalRead(OPTO)

void setup() {
  // put your setup code here, to run once:
  Serial.begin(9600);

  //add custom char;
  lcd.begin(8, 2);
  lcd.clear();
  lcd.createChar (0, next_ch);
  lcd.createChar (1, stop_ch);
  lcd.createChar (2, back_ch);

  // Print a message to the LCD.
  lcd.setCursor(0, 0);
  lcd.print("T12 v0.5");
  lcd.setCursor(0, 1);
  lcd.print(" by Ceez");  
  
  delay(2000);
  lcdSet_T();

  initTimer();
  // init variables
  bTipFail = true;

  bAirUpdate = true;
  bAir = true;
  target_T = eepromRead_T();
  bEnableOpto = (eepromRead_Opto()>0)? true: false;

  //init PWM for controlling Heat element
  initPWM_Tip();
  initOpto();
  EncoderSetup();
  
  //check if tip is plugged
  pinMode(CHECK_TIP, INPUT_PULLUP);
}


bool bIsLongPress = false;

// Do not use any blocking function such as delay
void loop() 
{
  if (bSetUpdate)
  {
    bSetUpdate = 0;
    lcdSet_T();      
    resetAirTick();
    eepromWrite_T(target_T);
  }
  
  if (bIsLongPress)
  {
    bIsLongPress = false;
    bEnableOpto = !bEnableOpto;
    updateOpto();
  }

  if (BT_PREV_STATE == LOW && millis() - btDown_tm > 3000)
  {
    bIsLongPress = true;
  }

  //check if tip is plugged
  if (digitalRead(CHECK_TIP)== HIGH) bTipFail = true;
  else bTipFail = false;

  if (bOptoCheck) 
  {
    bOptoCheck = false; //done update
    
    bSleep = isDocking();
    
    if (dock_last_status != bSleep && millis() - dock_tm > 500) // if docking status changed over 0.5s
    {
      dock_last_status = bSleep;    // update new docking status
      dock_tm = millis();           // write down timestamp only when docking
      if (bSleep == true && bEnableOpto == false) // only do thing when docking, not undocking and docking is OFF
      {
          if (dock_cnt <= 3)
          {
            dock_cnt++;
            if (dock_cnt >= 3)
            {
              bEnableOpto = true; // turn on opto feature
              updateOpto();
              dock_cnt = 0;
            }
          }
          if (dock_cnt > 3) dock_cnt = 3;
      }      
    }
    
    if (!bEnableOpto) //if opto disbale
    {
      bSleep = false;
    }
    // check for timeout and set corect temp in tipUpdate()

  }
  
  if (bHUpdate) 
  {
    bHUpdate = false; //done update
    bool m = tipUpdate();
    if (bTipFail) 
    {      
      lcdTipFail();
    }
    else 
    {
      if (!bSleep) lcd_T();  
      else lcdSleep();
    }
    
  }

  if (bAirUpdate)
  {
    bAirUpdate = false;
    bAir = !bAir;
    
    read_NTC();
    if (bAir) lcd_A();
    else lcdSet_T();
  }
}



////////////////////////////////
/// LCD write

void lcdTipFail()
{
  lcd.setCursor(0, 1);
  lcd.print("  FAIL  ");  
}

void lcdSleep()
{
  lcd.setCursor(0, 1);
  lcd.print(" SLEEP  ");  
}


void lcdOpto()
{
  lcd.setCursor(0, 0);
  lcd.print(" DOCKING");
  lcd.setCursor(0, 1);
  if (bEnableOpto) lcd.print("   ON   ");
  else lcd.print("   OFF  ");
}

void lcdSet_T()
{
  lcd.setCursor(0, 0);
  lcd.print("T");
  lcd.print((char)2);
  lcd.print(" ");
  lcd.print(target_T);
  lcd.print((char)223);
  lcd.print("C  ");
}

void lcd_T()
{
  lcd.setCursor(0, 1);
  lcd.print("H");
  lcd.print((char)0);
  lcd.print(" ");
  lcd.print(tip_T);
  lcd.print((char)223);
  lcd.print("C  ");
}
void lcd_A()
{
  lcd.setCursor(0, 0);
  lcd.print("Air ");
  air_T = read_NTC();
  lcd.print((int)air_T);
  lcd.print((char)223);
  lcd.print("C   ");
}

////////////////////////////////
// Read /write EEPROM
#define ADDR_H 1
#define ADDR_L 0
#define ADDR_OPTO 10

//#define ADDR_ONCE 2
#define DEFAULT_T 200
#define MAX_T MAX_TEMP
#define MIN_T 100



int16_t validate_T(int16_t T)
{
  if (T > MAX_T) return MAX_T;
  if (T < MIN_T) return MIN_T;
  return T;
}

//limit to 100degC
int16_t eepromRead_T()
{
  int16_t ret= 0;
  ret += EEPROM.read(ADDR_L);
  ret += EEPROM.read(ADDR_H)<<8;
  return validate_T(ret);
}

void eepromWrite_T(int16_t T)
{
  T = validate_T(T);  
  EEPROM.write(ADDR_L, T & 0xFF); //low byte
  EEPROM.write(ADDR_H, T >>8); //high byte
}

bool eepromRead_Opto()
{
  int ret = false;
  ret = EEPROM.read(ADDR_OPTO);
  if (ret == 0xFF) return true;
  if (ret > 0) return true;
  return false;
}

void eepromWrite_Opto(bool enable)
{
  if (enable) EEPROM.write(ADDR_OPTO, 1); 
  else EEPROM.write(ADDR_OPTO, 0);
}

void updateOpto()
{
  eepromWrite_Opto(bEnableOpto);
  lcdOpto();
  delay(1000);
  lcd_T();
  lcdSet_T();
}
  

////////////////////////////////
// T12 tip: read temp/ PWM out


//setup timer1 for PWM at D9
void initPWM_Tip()
{
  digitalWrite(TIP_PWM, HIGH);
  pinMode(TIP_PWM, OUTPUT);
  TCCR1A = _BV(COM1A1) | _BV(WGM10);
  TCCR1B = TCCR1B & B11111000 | B00000001;
  OCR1A = 0;
}


// pwm = 0 // turn off
void PWM_TipOut(int pwm)
{
  pwm &= 0xFF; //get only low byte
  OCR1A = (byte)pwm;
}

// Read T12 temp
int16_t read_T12()
{
  // x8 sample
  int32_t T=0;
  for (int8_t i=0;i<8; i++) T += analogRead(TIP_AN);
 
  // For TIP that has 8 OHM heater:
  // T = 0.403*(A0) + 49.60
  // T = 403*A0 + 50
  
  T = ((int32_t)403*T/1000) >>3;
  return (int16_t)T + 50;
}

// increase target temp by 1 degree or 10 degree
bool multi = true;

void flipMulti()
{
  multi = !multi;
}

void plus_T()
{
  if (multi) target_T += 10;
  else target_T += 1;
  target_T = validate_T(target_T);
  bSetUpdate = 1;
}

void minus_T()
{
  if (multi) target_T -= 10;
  else target_T -= 1;
  target_T = validate_T(target_T);
  bSetUpdate = 1;
}

// UPDATE T12 Temp
// close loop control from tip temperature feedback
bool tipUpdate()
{
  int pwm_power;
  PWM_TipOut(0); // Turn off Heater
  delay(100); //let the temp settle down, stray voltage goes away

  tip_T = read_T12();  
  int16_t dT = tip_T; // dT = amount of temperature to reach to target from current tip temperature

  //limit temp to sleep_T if sleep is acrive

  int16_t sleep_T = DOCK_T1;                                 // 200degC
  if (millis() - dock_tm > DOCK_TIMEOUT1) sleep_T = DOCK_T2; // 100degC
  if (millis() - dock_tm > DOCK_TIMEOUT2) sleep_T = DOCK_T3; // 0degC
  
  // sleep temperature should not exceed target temperature
  if (sleep_T > target_T) sleep_T = target_T;

  // if sleep is active
  if (bSleep) dT = sleep_T - tip_T; 
  else dT = target_T - tip_T;
  
  if (dT > 50) pwm_power = 255; // if over 50degC different, full power
  else 
  {
    if (dT<=0) pwm_power = 0;   // if Target T is lower than current T, power = 0
    else pwm_power = dT*255/50; // doing some PID thing (Proportional, Integral, Derivative), except without D (Derivative = predict the future)
  }

  // Some note: PID only works best with stable load, with unstable load like massive ground plane, PID will struggle a bit
  // so, slightly overshoot is more desirable and better response with high load

  if (tip_T>550 || tip_T <= 0) bTipFail = true;

  // If Tip reading is normal Turn on TIP
  if (!bTipFail) PWM_TipOut(pwm_power);
  
  if (pwm_power==0) return false; //not heating
  return true;
}

void initOpto()
{
  OPTO_OFF();
  pinMode(OPTO, INPUT_PULLUP);
  pinMode(IR_LED, OUTPUT);
  OPTO_ON();
}

////////////////////////////////
/// READ THERMISTOR

float read_NTC()
{
  float Vo=0;
  //read n times
  for (int i=0; i< NUMSAMPLES; i++) 
    Vo += analogRead(NTC_AN);
    
  Vo /= NUMSAMPLES; //averaging
  
  // convert to resistance R_NTC
  Vo = SERIES_RESISTOR /(1023/Vo  - 1);     // 10K * (ADC - 1) / 1023
    
  float NTC_temp;

  // T_NTC = 1/ [ ln(R_NTC/Ro) / B + 1/(To) ]  deg Kelvin
  // 1/T_NTC = ln(R_NTC /Ro) / B + 1/To, where T_NTC and To in Kelvin
 
  NTC_temp = Vo / NTC_NOMINAL;                    // (R/Ro)
  NTC_temp = log(NTC_temp);                       // ln(R/Ro)
  NTC_temp /= B_COEFF;                            // 1/B * ln(R/Ro)
  NTC_temp += 1.0 / (NTC_TEMP_NOMINAL + 273.15);  // + (1/To)
  NTC_temp = 1.0 / NTC_temp;                      // Invert
  NTC_temp -= 273.15;                             // convert to C

  return NTC_temp;
}

////////////////////////////////
/// TIMER STUFF

void resetAirTick()
{
  AirTick =0;
  bAirUpdate = false;
}

// Call every 50ms
ISR(TIMER2_OVF_vect)        
{
  TCNT2 = 1310;   // preload counter for 40Hz
  HeaterTick++;
  AirTick++;
  OptoTick++;
  
  if (HeaterTick > HEATER_RATE) //update every 10 ticks
  {
    HeaterTick =0;
    bHUpdate = true;
  }
  
  if (AirTick > AIR_RATE)   //update every 1000 ticks
  {
    resetAirTick();
    bAirUpdate = true;
  }
  
  if (OptoTick > OPTO_CHECK_RATE)   //update every 5 ticks
  {
    OptoTick = 0;
    bOptoCheck = true;
  }
}

/// Setup timer for 20Hz (or 50ms each INT event)
void initTimer()
{
  //initialize timer1 
  noInterrupts();           // disable all interrupts
  TCCR2A = 0;
  TCCR2B = 0;
  
  TCNT2 = 1310;            // preload timer 65536-16MHz/256/20Hz
  TCCR2B = TCCR2B & B11111000 | B00000111;    // 30.6Hz
  TIMSK2 |= (1 << TOIE1);   // enable timer overflow interrupt
  interrupts();             // enable all interrupts
}

////////////////////////////////
// Encoder


void EncoderSetup()
{
  pciSetup(ENCA);
  pciSetup(ENCB); 
  pciSetup(ENCBTN);
}

void pciSetup(byte pin)
{
  pinMode(pin, INPUT_PULLUP);
  *digitalPinToPCMSK(pin) |= bit (digitalPinToPCMSKbit(pin));  // enable pin
  PCIFR  |= bit (digitalPinToPCICRbit(pin)); // clear any outstanding interrupt
  PCICR  |= bit (digitalPinToPCICRbit(pin)); // enable interrupt for the group
}


// vector PCINT2_vect for for D0 to D7
ISR (PCINT2_vect) // handle pin change interrupt for D0 to D7 here
{
  //push down
  if (digitalRead(ENCBTN)==LOW && BT_PREV_STATE == HIGH) 
  {
    BT_PREV_STATE = LOW;
    btDown_tm = millis();
    // run button down event    
    return;
  }
  //release
  if (digitalRead(ENCBTN)==HIGH && BT_PREV_STATE == LOW) 
  {
    BT_PREV_STATE = HIGH;
    btUp_tm = millis();
    // run button up event

    if (btUp_tm - btDown_tm > 10 || btUp_tm - btDown_tm < 200) flipMulti();
 
    return;
  }


  A_STATE = digitalRead(ENCA);
  B_STATE = digitalRead(ENCB);
  
  if (A_STATE && B_STATE) //both HIGH, reset
  {
    RT_CCW = 0;
    RT_CW = 0;
    return;
  }
  
  if (A_STATE==LOW && B_STATE==HIGH && RT_CW==LOW) RT_CW = 1; //enter Rotation CW
  if (A_STATE==HIGH && B_STATE==LOW && RT_CCW==LOW) RT_CCW = 1; //enter Rotation CW

  // do rotate CW, call function or let the main thread do the job
  if (RT_CW==HIGH && A_STATE==HIGH && B_STATE==LOW) 
  {
    //if happens within 5ms, ignore it
    if (millis() - rot_next_tm < 5) return; 
    plus_T();
    rot_next_tm = millis();
  }
  if (RT_CCW==HIGH && A_STATE==LOW && B_STATE==HIGH) 
  {
    if (millis() - rot_prev_tm < 5) return; 
    minus_T();
    rot_prev_tm = millis();
  }
}

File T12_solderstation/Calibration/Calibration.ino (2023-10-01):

///////////////////////////////////////////////////////////////////////////////
// T12 solder station - This is used for calibration
//	Cee'z 30 Mar 2023
//  
//	///////////////
//	// 23*C-1023 //    Mosfet temp - ADC value
//	// TD-24*C   //    Tip plugged - Docking - Tip temperature
//	///////////////
//
///////////////////////////////////////////////////////////////////////////////
// Target MCU: ATMega328 - bootloader Arduino UNO
// Clock: Ext 16MHz
//
// Character LCD 8x2
//		Fn:      5V+    GND   Enable  RS    R/W   Contrast  DB4 DB5 DB6 DB7	
//		Pin no:	 2      1     6       4     5     3         11  12  13  14
//		Arduino: 5v+    GND   D6      D5    D7    pot-10k   D10 D8  D12 D11
//
// The gain: (470K/1K)+1 = 471 v/v
// Take from the chart
// T = 0.47*ADC + 45.98
// T = 0.47*(ADC + 97.83)
// new data:
// T = 0.403*ADC + 49.60


//#define _DEBUG
#include <avr/interrupt.h>
#include <EEPROM.h>

// new configuration
#include <LiquidCrystal.h>
#define LCD_EN 6
#define LCD_RS 5
#define LCD_RW 7
#define LCD_D4 10
#define LCD_D5 8 
#define LCD_D6 12
#define LCD_D7 11

LiquidCrystal lcd(LCD_RS, LCD_RW, LCD_EN, LCD_D4, LCD_D5, LCD_D6, LCD_D7);

// custom chars
byte nextc[8] = {B00000,B01000,B01100,B01110,B01110,B01100,B01000,B00000};
byte stopc[8] = {B00000,B11011,B11011,B11011,B11011,B11011,B11011,B00000};
byte backc[8] = {B00000,B00010,B00110,B01110,B01110,B00110,B00010,B00000};

bool bSetUpdate;
int16_t tip_T;
int16_t tip_ADC;
int16_t air_T;

#define CHECK_TIP A7

void setup() {
  // put your setup code here, to run once:
  Serial.begin(9600);

  //add custom char;
  lcd.begin(8, 2);
  lcd.clear();
  lcd.createChar (0, nextc);
  lcd.createChar (1, stopc);
  lcd.createChar (2, backc);

  // Print a message to the LCD.
  lcd.setCursor(0, 0);
  lcd.print("T12 v0.1");
  lcd.setCursor(0, 1);
  lcd.print("Calibrate");  
  delay(2000);
  lcd.setCursor(0, 0);
  lcd.print("        ");
  lcd.setCursor(0, 1);
  lcd.print("        ");
    
  //EncoderSetup();
  
  //check if tip is 
  //pinMode(CHECK_TIP, INPUT_PULLUP);
  
  initTimer();
  // init variables

  //init PWM for controlling Heat element
  //initPWM_Tip();
  initOpto();

  //bAirUpdate = true;
  //bAir = true;
  
  //target_T = eepromRead_T();

}


// do not use any blocking function such as delay
void loop() 
{
  if (bSetUpdate)
  {
    read_T12();
    lcd_ADC_T();
    lcd_T();
    air_T = read_NTC();
    lcd_A();
    bSetUpdate = false; //updated
  }
  //isDocking();
  //isTipPlug();
}



////////////////////////////////
/// LCD write


void lcd_ADC_T()
{
  lcd.setCursor(3, 0);
  lcd.print(" ");
  lcd.print(tip_ADC);
  lcd.print("    ");
}
void lcd_T()
{
  lcd.setCursor(2, 1);
  lcd.print(" ");
  lcd.print(tip_T);
  //lcd.print((char)223);
  lcd.print("C  ");
}

void lcd_A()
{
  lcd.setCursor(0, 0);
  lcd.print((int)air_T);
  lcd.print("C");
}

////////////////////////////////
// T12 tip: read temp/ PWM out

// for docking check
#define OPTO A2
#define IR_LED A3
#define DOCK_TEMPERATURE 100


#define TIP_AN A0 // tip voltage
#define TIP_PWM 9 // D9
//#define NUM_OF_SAMPLE 4
#define SLEEP_T 100 // sleep temperature 60*C

//setup timer1 for PWM at D9
void initPWM_Tip()
{
  pinMode(TIP_PWM, OUTPUT);
  TCCR1A = _BV(COM1A1) | _BV(WGM10);
  TCCR1B = TCCR1B & B11111000 | B00000001;
  OCR1A = 0;
}

// T = 0.47*ADC + 45.98
// T = 0.403*ADC + 49.60

// Read T12 temp
void read_T12()
{
  int32_t T=0;
  for (int i=0;i<8; i++)
    T += analogRead(TIP_AN);
  //T = T>>3;
  tip_ADC = T>>3; //average by 8 reading
  T = 403*tip_ADC + 45980;
  tip_T = (int16_t)T/1000;
  //return (int16_t)T;
}

// increase target temp
void initOpto()
{
  digitalWrite(IR_LED, LOW); //turn off IR_LED
  pinMode(OPTO, INPUT);
  pinMode(IR_LED, OUTPUT);
}

bool isDocking()
{
  digitalWrite(IR_LED, HIGH); //turn on IR_LED
  bool ret = !digitalRead(OPTO); //if LOW == SLEEP
  digitalWrite(IR_LED, LOW); //turn off IR_LED
  return ret;
}


////////////////////////////////
/// READ THERMISTOR

#define SERIES_RESISTOR 10000
#define VCC 4950
#define NTC_NOMINAL 10000      
#define NTC_TEMP_NOMINAL 25   

#define B_COEFF 3950

#define NUMSAMPLES 8
#define NTC_AN A1


float read_NTC()
{
  float Vo=0;
  //read n times
  for (int i=0; i< NUMSAMPLES; i++) 
    Vo += analogRead(NTC_AN);
    
  Vo /= NUMSAMPLES; //averaging
  
  // convert to resistance R_NTC
  Vo = SERIES_RESISTOR /(1023/Vo  - 1);     // 10K * (ADC - 1) / 1023
    
  float NTC_temp;

  // T_NTC = 1/ [ ln(R_NTC/Ro) / B + 1/(To) ]  deg Kelvin
  // 1/T_NTC = ln(R_NTC /Ro) / B + 1/To, where T_NTC and To in Kelvin
 
  NTC_temp = Vo / NTC_NOMINAL;                    // (R/Ro)
  NTC_temp = log(NTC_temp);                       // ln(R/Ro)
  NTC_temp /= B_COEFF;                            // 1/B * ln(R/Ro)
  NTC_temp += 1.0 / (NTC_TEMP_NOMINAL + 273.15);  // + (1/To)
  NTC_temp = 1.0 / NTC_temp;                      // Invert
  NTC_temp -= 273.15;                             // convert to C

  return NTC_temp;
}

////////////////////////////////
/// TIMER STUFF

uint16_t HeaterTick;
uint16_t AirTick;
uint16_t OptoTick;

// UPDATE RATE
// Heater 
#define HEATER_RATE 20
#define AIR_RATE 1000
#define OPTO_CHECK_RATE 5

void resetAirTick()
{
  //AirTick =0;
  //bAirUpdate = false;
}

// Call every 50ms
ISR(TIMER2_OVF_vect)        
{
  TCNT2 = 1310;   // preload counter for 20Hz
  HeaterTick++;
  AirTick++;
  OptoTick++;
  
  if (HeaterTick > HEATER_RATE) //update every 10 ticks
  {
    HeaterTick =0;
    bSetUpdate = true;
  }
}

/// Setup timer for 20Hz (or 50ms each INT event)
void initTimer()
{
  //initialize timer1 
  noInterrupts();           // disable all interrupts
  TCCR2A = 0;
  TCCR2B = 0;
  
  TCNT2 = 1310;            // preload timer 65536-16MHz/256/20Hz
  TCCR2B = TCCR2B & B11111000 | B00000111;    // 30.6Hz
  TIMSK2 |= (1 << TOIE1);   // enable timer overflow interrupt
  interrupts();             // enable all interrupts
}

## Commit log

2023-10-01 Add files via upload
    Update opto docking function:
    - Dock/undock 3 times would trigger docking function
    - Add 2 more sleep temperatures for better wake up response time:
    + Limit to 200degC after docking
    + Limit to 100degC after 120s docking
    + Turn off heater after 15 minutes
2023-10-01 Add files via upload
    Fix: only turn on Opto when doing check
    [Calibration.ino]
2023-10-01 Add files via upload
    - Clean up a bit and add more comments
    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
2023-10-07 Add files via upload
    - Improve using experience
    - Quicker heat up from sleep
2023-10-07 Add files via upload
    - Upgrade project to Kicad 7.0
    - Improve schematic details
    [SolderStation.kicad_pcb, SolderStation.kicad_sch]
2023-10-09 Add files via upload
    Problem:
    Flickering between sleep and working while not docking
    Possible cause:
    When power up sensor by GPIO, it takes some time to
    + ramp up voltage at IR-LED for it to fully blast IR beam
    + IR Diode to fully reverse conduct to get LOW level
    So digitalRead() of opto would frequently get HIGH randomly when it should get LOW
    Possible fixes:
    1- Turn on OPTO --> delay(10) --> read OPTO --> delay(10) --> turn off OPTO
    2- Turn on OPTO at all times instead of just turn on and off while checking.
    Since we read OPTO frequently (8 times/s), doing delay there is not optimal. Hence, solution 2 would work best, OPTO sensor would not consume much power anyh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
    [T12_solderstation.ino]
2025-08-24 Add files via upload
    Add standalone iron handle stand
    [iron handle stand - standalone - frame only.stl]
2026-06-01 Enhance README with LCD0802 16pin variant
    Updated the README to clarify the 16-pin version of LCD0802 installation and backlight modifications.
